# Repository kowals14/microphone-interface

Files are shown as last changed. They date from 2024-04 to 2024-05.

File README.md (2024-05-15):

# USB Microphone Interface
This repository holds all the necessary files for [team 12's ECE 477 project](https://engineering.purdue.edu/477grp12/).

## Project Description
Microphone Interface is a microphone interface intended to be used with analog audio microphones. This interface would apply various DSP effects to the audio and pass it to an analog output. Specifically, our device will implement the following functionality:
* Be powered via micro-USB.
* Receive an analog audio input via 3.5mm TRS jack.
* Apply the following user selectable and user controllable DSP effects:
    * Five band equalization
    * Distortion
    * Delay
*  Allow the user to navigate backwards and formwards via two push buttons.
*   Allow the user to manipulate the following DSP parameters via three rotary encoders:
    * Equalization (for each band):
      * Frequency
      * Width
      * Gain
    * Distortion:
      * Pre-Amp
      * Gain
      * Mix
    * Delay:
      * Time
      * Feedback
      * Mix
* Display the states of each DSP parameter (with a separate page for each effect) via a graphical user interface.
* Output the modified audio signal via a 3.5mm TRS jack.
  
## PROJECT SPECIFIC DESIGN REQUIREMENTS (PSDRS):
* PSDR #1 (Hardware): An ability to send and receive an audio signal to and from a codec and a microcontroller via I2S.
* PSDR #2 (Software): An ability to apply five band EQ, distortion, and delay effects via DSP on an input audio.
* PSDR #3 (Hardware): An ability to control DSP parameters using input to a microcontroller from a set of rotary encoders and buttons.
* PSDR #4 (Hardware): An ability for the microcontroller to interface with an LCD display via SPI.
* PSDR #5 (Software): An ability to provide a GUI to display DSP parameters and corresponding audio effects.

## STRETCH PSDRS:
* PSDR #6 (hardware): An ability to control parameters and interact with the user interface via capacitive touch screen.

## Files
* Final - STM32 Cube project containing the final version of the project.
* Current - Folder containing schematic and pcb files for Kicad

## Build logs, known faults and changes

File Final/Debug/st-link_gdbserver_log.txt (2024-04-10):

[0.000] initConfigParams():  Configuration flags start
[0.001] initConfigParams():   external-init                  false
[0.001] initConfigParams():   pend-halt-timeout              (null)
[0.001] initConfigParams():   halt                           false
[0.001] initConfigParams():   config-file                    ""
[0.001] initConfigParams():   persistent                     false
[0.001] initConfigParams():  +log-file                       "C:\Users\Kuba\STM32CubeIDE\workspace_1.14.0\Final\Debug\st-link_gdbserver_log.txt"
[0.001] initConfigParams():  +log-level                      31
[0.001] initConfigParams():  +port-number                    61234
[0.001] initConfigParams():  +verbose                        true
[0.001] initConfigParams():   refresh-delay                  15
[0.001] initConfigParams():  +verify                         true
[0.001] initConfigParams():  +swd                            true
[0.001] initConfigParams():   swo-port                       61234
[0.001] initConfigParams():   cpu-clock                      8000000
[0.001] initConfigParams():   swo-clock-div                  128
[0.001] initConfigParams():  +initialize-reset               true
[0.001] initConfigParams():   debuggers                      false
[0.001] initConfigParams():   serial-number                  ""
[0.001] initConfigParams():  +apid                           0
[0.001] initConfigParams():   attach                         false
[0.001] initConfigParams():   shared                         false
[0.001] initConfigParams():   erase-all                      false
[0.001] initConfigParams():   memory-map                     ""
[0.001] initConfigParams():   ext-memory-loaders             false
[0.001] initConfigParams():   extload_init                   (null)
[0.001] initConfigParams():   extload                        (null)
[0.001] initConfigParams():  +stm32cubeprogrammer-path       "C:\ST\STM32CubeIDE_1.14.0\STM32CubeIDE\plugins\com.st.stm32cube.ide.mcu.externaltools.cubeprogrammer.win32_2.1.100.202311100844\tools\bin"
[0.001] initConfigParams():   temp-path                      ""
[0.001] initConfigParams():   preserve-temps                 false
[0.001] initConfigParams():   frequency                      0
[0.001] initConfigParams():   licenses                       false
[0.001] initConfigParams():   ignore-rest                    false
[0.001] initConfigParams():   version                        false
[0.001] initConfigParams():   help                           false
[0.001] initConfigParams():  Configuration flags end
[0.004] init():  STMicroelectronics ST-LINK GDB server. Version 7.5.0
Copyright (c) 2023, STMicroelectronics. All rights reserved.
[0.022] openDevice():  COM frequency = 4000 kHz
[0.022] openDevice():  Target connection mode: Under reset
[0.545] readFromTarget():  Reading ROM table for AP 0 @0xe00fdfd0
[0.548] reset_hw_wtchpt_module():  Hardware watchpoint supported by the target 
[0.552] initContext():  ST-LINK Firmware version : V2J43S7
[0.552] initContext():  Device ID: 0x449
[0.552] initContext():  PC: 0x8002bb8
[0.552] Device_GetStatus():  ST-LINK device status: HALT_MODE
[0.553] initContext():  ST-LINK detects target voltage = 3.32 V
[0.553] initContext():  ST-LINK device status: HALT_MODE
[0.553] initServerContext():  ST-LINK device initialization OK
[0.553] pollAndNotifyRun():  Stm32Device, pollAndNotify running...
[0.555] updateState():  SwvSrv state change: 0 -> 1
[0.555] WaitConnection():  Waiting for connection on port 61234...
[0.555] WaitConnection():  Waiting for connection on port 61235...
[4.307] WaitConnection():  Accepted connection on port 61234...
[4.307] WaitConnection():  Waiting for connection on port 61234...
[4.307] run():  GDB session thread running
[4.307] handleSessionEvent():  GdbSessionManager, session started: 1
[4.322] read():  <756> Rx: +
[4.322] read():  <756> Rx: $qSupported:multiprocess+;swbreak+;hwbreak+;qRelocInsn+;fork-events+;vfork-events+;exec-events+;vContSupported+;QThreadEvents+;no-resumed+;memory-tagging+#ec
[4.322] write():  <756> Tx: +
[4.322] write():  <756> Tx: $PacketSize=4000;qXfer:memory-map:read+;qXfer:features:read+;QStartNoAckMode+;QNonStop+;qXfer:threads:read+;hwbreak+;swbreak+#f3
[4.322] read():  <756> Rx: +
[4.322] read():  <756> Rx: $vMustReplyEmpty#3a
[4.322] write():  <756> Tx: +
[4.322] write():  <756> Tx: $#00
[4.322] read():  <756> Rx: +$QStartNoAckMode#b0
[4.338] write():  <756> Tx: +
[4.338] write():  <756> Tx: $OK#9a
[4.338] read():  <756> Rx: +
[4.338] read():  <756> Rx: $Hg0#df
[4.338] write():  <756> Tx: $#00
[4.338] read():  <756> Rx: $qXfer:features:read:target.xml:0,1000#0c
[4.338] write():  <756> Tx: $l<?xml version="1.0"?><!-- Copyright (C) 2009, 2010, 2011 Free Software Foundation, Inc.     Copying and distribution of this file, with or without modification,     are permitted in any medium without royalty provided the copyright     notice and this notice are preserved.  --><!DOCTYPE target SYSTEM "gdb-target.dtd"><target><feature name="org.gnu.gdb.arm.m-profile">  <reg name="r0" bitsize="32"/>  <reg name="r1" bitsize="32"/>  <reg name="r2" bitsize="32"/>  <reg name="r3" bitsize="32"/>  <reg name="r4" bitsize="32"/>  <reg name="r5" bitsize="32"/>  <reg name="r6" bitsize="32"/>  <reg name="r7" bitsize="32"/>  <reg name="r8" bitsize="32"/>  <reg name="r9" bitsize="32"/>  <reg name="r10" bitsize="32"/>  <reg name="r11" bitsize="32"/>  <reg name="r12" bitsize="32"/>  <reg name="sp" bitsize="32" type="data_ptr"/>  <reg name="lr" bitsize="32"/>  <reg name="pc" bitsize="32" type="code_ptr"/>  <reg name="xpsr" bitsize="32" regnum="25"/></feature><feature name="org.gnu.gdb.arm.vfp">  <reg name="d0" bitsize="64" type="ieee_double"/>  <reg name="d1" bitsize="64" type="ieee_double"/>  <reg name="d2" bitsize="64" type="ieee_double"/>  <reg name="d3" bitsize="64" type="ieee_double"/>  <reg name="d4" bitsize="64" type="ieee_double"/>  <reg name="d5" bitsize="64" type="ieee_double"/>  <reg name="d6" bitsize="64" type="ieee_double"/>  <reg name="d7" bitsize="64" type="ieee_double"/>  <reg name="d8" bitsize="64" type="ieee_double"/>  <reg name="d9" bitsize="64" type="ieee_double"/>  <reg name="d10" bitsize="64" type="ieee_double"/>  <reg name="d11" bitsize="64" type="ieee_double"/>  <reg name="d12" bitsize="64" type="ieee_double"/>  <reg name="d13" bitsize="64" type="ieee_double"/>  <reg name="d14" bitsize="64" type="ieee_double"/>  <reg name="d15" bitsize="64" type="ieee_double"/>  <reg name="fpscr" bitsize="32" type="int" group="float"/></feature><feature name="org.gnu.gdb.arm.m-system">  <reg name="primask" bitsize="32" regnum="93"/>  <reg name="basepri" bitsize="32" regnum="94"/>  <reg name="faultmask" bitsize="32" regnum="95"/>  <reg name="control" bitsize="32" regnum="96"/>  <reg name="msp" bitsize="32" type="data_ptr" regnum="97"/>  <reg name="psp" bitsize="32" type="data_ptr" regnum="98"/></feature></target>#ad
[4.340] read():  <756> Rx: $QNonStop:0#8c
[4.340] write():  <756> Tx: $OK#9a
[4.340] read():  <756> Rx: $qTStatus#49
[4.340] write():  <756> Tx: $#00
[4.340] read():  <756> Rx: $?#3f
[4.340] write():  <756> Tx: $S05#b8
[4.341] read():  <756> Rx: $qXfer:threads:read::0,1000#92
[4.341] write():  <756> Tx: $l<?xml version="1.0"?><threads><thread id="1" core="0" name="main"></thread></threads>#f7
[4.341] read():  <756> Rx: $qAttached#8f
[4.341] write():  <756> Tx: $#00
[4.341] read():  <756> Rx: $Hc-1#09
[4.341] write():  <756> Tx: $#00
[4.341] read():  <756> Rx: $qC#b4
[4.341] write():  <756> Tx: $QC1#c5
[4.341] read():  <756> Rx: $qOffsets#4b
[4.341] write():  <756> Tx: $#00
[4.342] read():  <756> Rx: $g#67
[4.352] write():  <756> Tx: $0000000000000000000000000000000000000000000000000000000000000000000000000000000000000000000000000000000000000520ffffffffb82b000800000001000000000000000000000000000000000000000000000000000000000000000000000000000000000000000000000000000000000000000000000000ffffffff000000000000000000000000000000000000000000000000000000000000000000000000000000000000000000000000000000000000000000000000ffffffff00000000000000000000000000000000000000000000052000000000#95
[4.352] read():  <756> Rx: $qXfer:memory-map:read::0,1000#ab
[4.352] write():  <756> Tx: $l<?xml version="1.0"?>\x0a<!DOCTYPE memory-map\x0a          PUBLIC "+//IDN gnu.org//DTD GDB Memory Map V1.0//EN"\x0a                 "http://sourceware.org/gdb/gdb-memory-map.dtd">\x0a<memory-map>\x0a<memory type="ram" start="0x0" length="0x200000"/>\x0a<memory type="flash" start="0x200000" length="0x100000">\x0a<property name="blocksize">0x8000</property>\x0a</memory>\x0a<memory type="ram" start="0x300000" length="0x7d00000"/>\x0a<memory type="flash" start="0x8000000" length="0x100000">\x0a<property name="blocksize">0x8000</property>\x0a</memory>\x0a<memory type="ram" start="0x8100000" length="0xf7efffff"/>\x0a</memory-map>#bd
[4.353] read():  <756> Rx: $m8020228,2#31
[4.353] handlePacket():  Reading 0x2 bytes of memory from addr 0x8020228 
[4.353] write():  <756> Tx: $022c#f7
[4.354] read():  <756> Rx: $qXfer:threads:read::0,1000#92
[4.354] write():  <756> Tx: $l<?xml version="1.0"?><threads><thread id="1" core="0" name="main"></thread></threads>#f7
[4.354] read():  <756> Rx: $m8002bb8,4#93
[4.354] handlePacket():  Reading 0x4 bytes of memory from addr 0x8002bb8 
[4.354] write():  <756> Tx: $dff834d0#63
[4.355] read():  <756> Rx: $m8002bb8,2#91
[4.355] handlePacket():  Reading 0x2 bytes of memory from addr 0x8002bb8 
[4.355] write():  <756> Tx: $dff8#68
[4.356] read():  <756> Rx: $m8002bba,2#ba
[4.356] handlePacket():  Reading 0x2 bytes of memory from addr 0x8002bba 
[4.356] write():  <756> Tx: $34d0#fb
[4.357] read():  <756> Rx: $qSymbol::#5b
[4.357] write():  <756> Tx: $#00
[4.358] read():  <756> Rx: $qXfer:threads:read::0,1000#92
[4.358] write():  <756> Tx: $l<?xml version="1.0"?><threads><thread id="1" core="0" name="main"></thread></threads>#f7
[4.358] read():  <756> Rx: $qRcmd,5265616441504578203078302030784638#08
[4.359] write():  <756> Tx: $4f2e4b2e3a307865303066643030330a#88
[4.359] read():  <756> Rx: $qXfer:threads:read::0,1000#92
[4.359] write():  <756> Tx: $l<?xml version="1.0"?><threads><thread id="1" core="0" name="main"></thread></threads>#f7
[4.360] read():  <756> Rx: $qRcmd,526561644d656d41502030783020307845303046444644302030783820307830#64
[4.361] write():  <756> Tx: $4f2e4b2e3a3078302c3078302c3078302c3078302c307834392c3078342c307831612c3078300a#1a
[4.400] read():  <756> Rx: $qXfer:threads:read::0,1000#92
[4.400] write():  <756> Tx: $l<?xml version="1.0"?><threads><thread id="1" core="0" name="main"></thread></threads>#f7
[4.400] read():  <756> Rx: $qXfer:threads:read::0,1000#92
[4.400] write():  <756> Tx: $l<?xml version="1.0"?><threads><thread id="1" core="0" name="main"></thread></threads>#f7
[6.411] WaitConnection():  Accepted connection on port 61234...
[6.411] WaitConnection():  Waiting for connection on port 61234...
[6.411] run():  GDB session thread running
[6.411] handleSessionEvent():  GdbSessionManager, session started: 2
[6.427] read():  <788> Rx: +
[6.427] read():  <788> Rx: $qSupported:multiprocess+;swbreak+;hwbreak+;qRelocInsn+;fork-events+;vfork-events+;exec-events+;vContSupported+;QThreadEvents+;no-resumed+;memory-tagging+#ec
[6.427] write():  <788> Tx: +
[6.427] write():  <788> Tx: $PacketSize=4000;qXfer:memory-map:read+;qXfer:features:read+;QStartNoAckMode+;QNonStop+;qXfer:threads:read+;hwbreak+;swbreak+#f3
[6.427] read():  <788> Rx: +$vMustReplyEmpty#3a
[6.442] write():  <788> Tx: +
[6.442] write():  <788> Tx: $#00
[6.442] read():  <788> Rx: +
[6.442] read():  <788> Rx: $QStartNoAckMode#b0
[6.442] write():  <788> Tx: +
[6.442] write():  <788> Tx: $OK#9a
[6.442] read():  <788> Rx: +$Hg0#df
[6.457] write():  <788> Tx: $#00
[6.457] read():  <788> Rx: $qXfer:features:read:target.xml:0,1000#0c
[6.457] write():  <788> Tx: $l<?xml version="1.0"?><!-- Copyright (C) 2009, 2010, 2011 Free Software Foundation, Inc.     Copying and distribution of this file, with or without modification,     are permitted in any medium without royalty provided the copyright     notice and this notice are preserved.  --><!DOCTYPE target SYSTEM "gdb-target.dtd"><target><feature name="org.gnu.gdb.arm.m-profile">  <reg name="r0" bitsize="32"/>  <reg name="r1" bitsize="32"/>  <reg name="r2" bitsize="32"/>  <reg name="r3" bitsize="32"/>  <reg name="r4" bitsize="32"/>  <reg name="r5" bitsize="32"/>  <reg name="r6" bitsize="32"/>  <reg name="r7" bitsize="32"/>  <reg name="r8" bitsize="32"/>  <reg name="r9" bitsize="32"/>  <reg name="r10" bitsize="32"/>  <reg name="r11" bitsize="32"/>  <reg name="r12" bitsize="32"/>  <reg name="sp" bitsize="32" type="data_ptr"/>  <reg name="lr" bitsize="32"/>  <reg name="pc" bitsize="32" type="code_ptr"/>  <reg name="xpsr" bitsize="32" regnum="25"/></feature><feature name="org.gnu.gdb.arm.vfp">  <reg name="d0" bitsize="64" type="ieee_double"/>  <reg name="d1" bitsize="64" type="ieee_double"/>  <reg name="d2" bitsize="64" type="ieee_double"/>  <reg name="d3" bitsize="64" type="ieee_double"/>  <reg name="d4" bitsize="64" type="ieee_double"/>  <reg name="d5" bitsize="64" type="ieee_double"/>  <reg name="d6" bitsize="64" type="ieee_double"/>  <reg name="d7" bitsize="64" type="ieee_double"/>  <reg name="d8" bitsize="64" type="ieee_double"/>  <reg name="d9" bitsize="64" type="ieee_double"/>  <reg name="d10" bitsize="64" type="ieee_double"/>  <reg name="d11" bitsize="64" type="ieee_double"/>  <reg name="d12" bitsize="64" type="ieee_double"/>  <reg name="d13" bitsize="64" type="ieee_double"/>  <reg name="d14" bitsize="64" type="ieee_double"/>  <reg name="d15" bitsize="64" type="ieee_double"/>  <reg name="fpscr" bitsize="32" type="int" group="float"/></feature><feature name="org.gnu.gdb.arm.m-system">  <reg name="primask" bitsize="32" regnum="93"/>  <reg name="basepri" bitsize="32" regnum="94"/>  <reg name="faultmask" bitsize="32" regnum="95"/>  <reg name="control" bitsize="32" regnum="96"/>  <reg name="msp" bitsize="32" type="data_ptr" regnum="97"/>  <reg name="psp" bitsize="32" type="data_ptr" regnum="98"/></feature></target>#ad
[6.458] read():  <788> Rx: $QNonStop:0#8c
[6.458] write():  <788> Tx: $OK#9a
[6.459] read():  <788> Rx: $qTStatus#49
[6.459] write():  <788> Tx: $#00
[6.459] read():  <788> Rx: $?#3f
[6.459] write():  <788> Tx: $S05#b8
[6.459] read():  <788> Rx: $qXfer:threads:read::0,1000#92
[6.459] write():  <788> Tx: $l<?xml version="1.0"?><threads><thread id="1" core="0" name="main"></thread></threads>#f7
[6.459] read():  <788> Rx: $qAttached#8f
[6.459] write():  <788> Tx: $#00
[6.459] read():  <788> Rx: $Hc-1#09
[6.460] write():  <788> Tx: $#00
[6.460] read():  <788> Rx: $qC#b4
[6.460] write():  <788> Tx: $QC1#c5
[6.460] read():  <788> Rx: $qOffsets#4b
[6.460] write():  <788> Tx: $#00
[6.460] read():  <788> Rx: $g#67
[6.471] write():  <788> Tx: $0000000000000000000000000000000000000000000000000000000000000000000000000000000000000000000000000000000000000520ffffffffb82b000800000001000000000000000000000000000000000000000000000000000000000000000000000000000000000000000000000000000000000000000000000000ffffffff000000000000000000000000000000000000000000000000000000000000000000000000000000000000000000000000000000000000000000000000ffffffff00000000000000000000000000000000000000000000052000000000#95
[6.471] read():  <788> Rx: $qXfer:memory-map:read::0,1000#ab
[6.472] write():  <788> Tx: $l<?xml version="1.0"?>\x0a<!DOCTYPE memory-map\x0a          PUBLIC "+//IDN gnu.org//DTD GDB Memory Map V1.0//EN"\x0a                 "http://sourceware.org/gdb/gdb-memory-map.dtd">\x0a<memory-map>\x0a<memory type="ram" start="0x0" length="0x200000"/>\x0a<memory type="flash" start="0x200000" length="0x100000">\x0a<property name="blocksize">0x8000</property>\x0a</memory>\x0a<memory type="ram" start="0x300000" length="0x7d00000"/>\x0a<memory type="flash" start="0x8000000" length="0x100000">\x0a<property name="blocksize">0x8000</property>\x0a</memory>\x0a<memory type="ram" start="0x8100000" length="0xf7efffff"/>\x0a</memory-map>#bd
[6.472] read():  <788> Rx: $m8020228,2#31
[6.472] handlePacket():  Reading 0x2 bytes of memory from addr 0x8020228 
[6.473] write():  <788> Tx: $022c#f7
[6.473] read():  <788> Rx: $qXfer:threads:read::0,1000#92
[6.473] write():  <788> Tx: $l<?xml version="1.0"?><threads><thread id="1" core="0" name="main"></thread></threads>#f7
[6.474] read():  <788> Rx: $m8002bb8,4#93
[6.474] handlePacket():  Reading 0x4 bytes of memory from addr 0x8002bb8 
[6.474] write():  <788> Tx: $dff834d0#63
[6.475] read():  <788> Rx: $m8002bb8,2#91
[6.475] handlePacket():  Reading 0x2 bytes of memory from addr 0x8002bb8 
[6.475] write():  <788> Tx: $dff8#68
[6.475] read():  <788> Rx: $m8002bba,2#ba
[6.476] handlePacket():  Reading 0x2 bytes of memory from addr 0x8002bba 
[6.476] write():  <788> Tx: $34d0#fb
[6.477] read():  <788> Rx: $qSymbol::#5b
[6.477] write():  <788> Tx: $#00
[6.504] read():  <756> Rx: $vFlashErase:08000000,00028000#cc
[6.504] handleFlashPacket():  FlashErase skipped (Will be performed at flash done)
[6.504] write():  <756> Tx: $OK#9a
[6.504] read():  <756> Rx: $vFlashWrite:8000000:\x00\x00\x05 \xff+\x00\x08y)\x00\x08\x7f)\x00\x08\xff)\x00\x08\xff)\x00\x08\xff)\x00\x08\x00\x00\x00\x00\x00\x00\x00\x00\x00\x00\x00\x00\x00\x00\x00\x00\xff)\x00\x08\xff)\x00\x08\x00\x00\x00\x00\xff)\x00\x08\xff)\x00\x08\x09,\x00\x08\x09,\x00\x08\x09,\x00\x08\x09,\x00\x08\x09,\x00\x08\xff)\x00\x08\x09,\x00\x08\x09,\x00\x08\x09,\x00\x08\x09,\x00\x08\x09,\x00\x08\x09,\x00\x08\x09,\x00\x08\x09,\x00\x08\x09,\x00\x08\x09,\x00\x08\x09,\x00\x08\x09,\x00\x08\x09,\x00\x08\x09,\x00\x08\x09,\x00\x08\x09,\x00\x08\x09,\x00\x08\x09,\x00\x08\x09,\x00\x08\x09,\x00\x08\x09,\x00\x08\x09,\x00\x08\xff)\x00\x08\x09,\x00\x08\x09,\x00\x08\x09,\x00\x08\x09,\x00\x08\x09,\x00\x08\x09,\x00\x08\x09,\x00\x08\x09,\x00\x08\x09,\x00\x08\x09,\x00\x08\x09,\x00\x08\x09,\x00\x08\x09,\x00\x08\x09,\x00\x08\x09,\x00\x08\x09,\x00\x08\xff)\x00\x08\x09,\x00\x08\x09,\x00\x08\x09,\x00\x08\x09,\x00\x08\x09,\x00\x08\x09,\x00\x08\x09,\x00\x08\x09,\x00\x08\x09,\x00\x08\x09,\x00\x08\x09,\x00\x08\x05}\x0a\x00\x08\x09,\x00\x08\x09,\x00\x08\x19}\x0a\x00\x08\x09,\x00\x08\x09,\x00\x08\x09,\x00\x08\x09,\x00\x08\x09,\x00\x08\x09,\x00\x08\x09,\x00\x08-}\x0a\x00\x08\x09,\x00\x08\x09,\x00\x08\x09,\x00\x08\x09,\x00\x08\x09,\x00\x08\x09,\x00\x08\x09,\x00\x08\x09,\x00\x08\x09,\x00\x08\x09,\x00\x08\x00\x00\x00\x00\x09,\x00\x08\x09,\x00\x08\x09,\x00\x08\x09,\x00\x08\x09,\x00\x08\x09,\x00\x08\x09,\x00\x08\x09,\x00\x08\x09,\x00\x08\x09,\x00\x08\x09,\x00\x08\x09,\x00\x08\x09,\x00\x08\x09,\x00\x08\x09,\x00\x08\x09,\x00\x08\x09,\x00\x08\x09,\x00\x08#23
[6.505] handleFlashPacket():  Flash write: Address= 0x8000000, Length=456
[6.505] write():  <756> Tx: $OK#9a
[6.506] read():  <756> Rx: $vFlashWrite:80001d0:\x10\xff\x05L}\x03x3\xff\x04K\x13\xff\x04H\xff\xff\x00\xff\x01}\x03}\x03p\x10\xff0\x01\x00 \x00\x00\x00\x00l:\x02\x08\x08\xff\x03K\x1b\xff\x03I\x03H\xff\xff\x00\xff\x08\xff\x00\x00\x00\x004\x01\x00 l:\x02\x08\x01\xff\xff\x01\x10}\x0a+\xff\x10\xff\x07\x0f\x08\xff\x10\xff\x01;\x01:\xffB-\xff\x10\xff\x07\x0fB\xff\xff\xff\xff\xffA\xff\x01!A\xff\x01A"\xff\x07\x04\x7f\xff\x00\x07\x00}\x03\xff\xff\x02V\x08<\xff\xff\x01\x05\xff\xff\x01\x06\xff\xffG\xff\xff\xff\xff\xff\xff\xffG\xff\xff\xff\xff\xff\xff\xff\xff\xff\xff\xff\x01\xff\xff\x01\x02\xff\x07\x022\xff\x10\xff\x01;\x01:\xff\xff\x01\x03\x13\xff\xff\xff\x00 pG\x018pG\x00-\x06\xff5F\x038\x078\x15\xff\x01\x0f\x07\xff\x010\x15\xff\xff\x7f\x02\xff\x010\x15\xff\xff?\x010\xff\xff\x018pG\x00\xff\xff\xff\x00A\x02\xff\x00\xff\xff\xff\x00C0\xffO\xffA\x04O\xffC\x05\xff\xff\x05\x0f\x08\xff\xff\xff\x02\x0f\x1f\xffT\xff\x00\x0cU\xff\x02\x0c\x7f\xffd\\\x7f\xffe\\\x00\xff\xff\xffO\xffTT\xff\xffUU\xff\xffmB\x0c\xff,D\xff\xff\x02\x02\xff\xff\x03\x03\xff\xff\x00\x00\xff\xff\x01\x01\xff\xff\x02\x02\xff\xff\x03\x036-\xff\xff0\xff\x11\xff\x00OO\xff\x011O\xff\xff\x1cL\xff\x111\x02\xff@Ba\xffA\x01\x13\xff\x00OO\xff\x033L\xff\x133\x02\xffRBc\xffC\x03\xff\xff\x05\x0f\x00\xff\xff\xff\xff\xff\x01\x04\xff\xff \x0e\x0d\xff\x02\xff\x0e\xff"\xff\x05\xff\xff\x18A\xff\x00\x01\x03\xff\x0e\xff\xff\x18C\xff\x05\xffYA\x0e\xff\xff\xff \x05\x0e\xff \x0e\x01}\x0a\x03\xff\x0e\xff(\xffL\xff\x02\x0cC\xff\x05\xff\xff\x18Q\xff\xffq\x01\xff\x00E\x07\xffO\xff\x00\x0e\xff\xff\x00\x0c~\xff\x00\x00n\xff\x01\x01\xff\xff\xff\x1f\x1b\xff\xff\xff\x00\x1f\x0c\xffI\x08_\xff0\x00O\xff<\x0c\x04\xff\x01\x04O\xffDR\x12\xff\xff\x0f\xff\xff\xff\xff\xff\xff\x00O\x08\xff_\xffP\x0cP\xff\x00\x00A\xff\x04QA\xff\x05\x010\xff_\xffL\x0c@AA\xff\x01\x01\x01<(\xff\xff\xff\xff\x1f\xff\xff\xff\xff\x00\x0f\x04\xff\x01F\x00 \xff\xff\xff\xff\x08\xff 3\xff\xff\x0b\x03\xff\xff \x02\x0c\xff\x0c2\x08\xff\x02\xff\x14\x0c\xff\xff\x0c\x02\x01\xff\x0c\xff!\xff\x02\xff\x0c\xff\x02\xff\x14\x02\xff\xff\xff\xff \x0c\x01\xff\x02\xff \xff\x0c\xff\xff\xffA\xff\x0c\x01\xff@\xff\x1a\xff\xff\x01\xff\x04Q)C0\xffo\xff\x04\x04\x1f<\x1c\xff\x0c4\x0e\xff\x04\xff\x14\x04\xff\xff \x02 \xff\x04\xff\x01\xff\x02\xff@\xff\x03\x00!\xff\x04\xffE\xff\x03\x010\xff\xff\xff\x0c\x04\xff\xff \x02 \xff\x02\xff\x01\xff\x04\xff@\xff\x03\x00)F0\xff!\xff\x04\xff)F0\xff\xff\xff\x00\x0f\xff\xff\xff\x13\x06\xff\xff\xff\xff\x11\x014\x01=N\xff\x7f\xffd\\\x18\xff\x7f\xffe\\)\xff\xff\xff\x05\x0f\x08\xff\xff\xff\x02\x0f\x05\xffT\xff\x00\x0c\x04\xff\x19F\x10F0\xff\xff\xff\x03\x0f\x1e\xff\x00!\x00 0\xff_\xffT\\\x05\xff@\x00IA(\xffA\xff\x00A0\xff\x14\xff\xff\x04<\xff\x01\xff\xff\x110\xff\x01\xff\x00EE\xff\xffAA\xffp\x01O\xff\x00\x000\xff\x7f\xffd\\\x1a\xff\x19F\x10F\x7f\xffe\\\x1c\xff\x0bF\x02FP\xff\x014\x06\xffR\xff\x035\xff\xff\x03\x0fA\xff\x00!0\xff\x00\xff\xff\xff\x00\x0f\x04\xff\x00!pG0\xffO\xff\xffd\x04\xff2\x04O\xff\x00\x05O\xff\x00\x01P\xff\x00\xff\xff\xff\x00\x0f\x04\xff\x00!pG0\xffO\xff\xffd\x04\xff2\x04\x10\xff\x00EH\xff@BO\xff\x00\x01>\xff\x00\xffB\x00O\xff\xff\x01O\xff1\x01O\xff\x02p\x1f\xff\x12\xff\x7fC\xff\xff\x7fO\xff\xff`QpG2\xff\x7fB\x08\xffpG\xff\xff\x7fO\x04\xffA\xff\x00!pG0\xffO\xff`t\x01\xff\x00E!\xff\x00A\x1c\xff\x00\xffP\xff\x01\x02\x08\xffpG0\xffO\xff\x00\x05\x0a\xffP\xff\x01\x02\x08\xffpG0\xff\x11\xff\x00E\x02\xff@Ba\xffA\x01O\xff\xffd\x04\xff2\x04_\xff\xff\\?\xff\xff\xffO\xff\x03\x02_\xff\xff\x0c\x18\xff\x032_\xff\xff\x0c\x18\xff\x032\x02\xff\xff\x02\xff\xff \x03\x00\xff\x03\xff \xff\x02\xff\x01\xff\x03\xff@\xff\x0e\x00!\xff\x02\xff\x14D\xff\xff\x00\xffp\xffO\xff\xff\x0cL\xff\xffl\x1c\xff\x11T\x1d\xff\x1c\xff\x13U\xff\xff\x0c\x0f\xff\xff\x0c\x0f\x00\xff\xff\xff,D\xff\xff\x03\x06!\xffLQ}\x03\xffLSP\xff\x015\x18\xffR\xff\x035A\xff\xff\x11C\xff\xff\x138\xff\xff\xff\x02\xffO\xff\x00\x05\xff\xff\x02\xff\x06\xff\x00B\xff\xff\x03\xffO\xff\x00\x06\xff\xff\x03V\xff\xff\x00\x0f\x18\xffN\xff\x01\x0e\xff\xff\xff\x04\xff\xff\x00\x7fd\xff@t\x04\xff_\xffN\x0emAF\xff\x06\x06B\xff\xff!A\xffUQO\xff\xff @\xff^PO\xff\xff.\xff\xff\xff\x0c\xff\xff\xff\xff\xffo\x1e\xff\xff\xff\x00O\x08\xff_\xffP\x0eP\xff\x00\x00A\xff\x04Qp\xff\x06\xff\x00FF\xff\x01\x01@\xff\x02\x00\xff\xff\x03\x01\xff\xff\\\x04\xff\xff\xff\xff\x0c\x05A\xff\x04Qp\xffA\xff\xff\x11O\xff\x00\x0e\x01<\x00\xff\xff\xff\x14\xff6\x0f\xff\xff\x00 \x01\xff\x00Ap\xff\xff\xff\x00\x04 <5\xff\x0c4\x1b\xff\x04\xff\x14\x04\xff\xff \x05\x00\xff\x05\xff \xff\x04\xff\x01\xff\x05\xff@\xff\x02\x00\x01\xff\x00B!\xff\x00A\x10\xff\xffp!\xff\x04\xffB\xff\x06\x01^\xffC\x0e\x08\xff \xff\xffpp\xff\xff\xff\x0c\x04\xff\xff \x05\x00\xff\x04\xff \xff\x05\xff\x01\xff\x04\xff@\xff\x02\x00\x01\xff\x00A\x10\xff\xffpA\xff\x00\x01^\xffC\x0e\x08\xff \xff\xffpp\xff\xff\xff \x05\x00\xff\x05\xffN\xff\x02\x0e \xff\x04\xff\x01\xff\x05\xffC\xff\x02\x03!\xff\x04\xff\x01\xff\x00A!\xff\x04\xff \xff\x02\x00\x00\xff\xffp^\xffC\x0e\x08\xff \xff\xffpp\xff\xff\xff\x00\x0f\x0f\xff\x01\xff\x00F@\x00A\xff\x01\x01\x11\xff\xff\x1f\x08\xff\x01<\xff\xffA\xff\x06\x01\xff\xff\x00\x0f\x18\xffpG\x03\xff\x00FR\x00C\xff\x03\x03\x13\xff\xff\x1f\x08\xff\x01=\xff\xffC\xff\x06\x03pG\xff\xff\x0c\x0f\x0c\xff\x13U\x18\xff\xff\xff\x0c\x0f\x0c\xffP\xffA\x06\x18\xffR\xffC\x06\xff\xff\xff\xff\x03\x01\x01\xff\x00AO\xff\x00\x00p\xffP\xffA\x06\x06\xff\x10F\x19FR\xffC\x06\x19\xff\xff\xff\x0c\x0f\x02\xffP\xff\x016\x13\xff\xff\xff\x0c\x0f\x05\xffR\xff\x036\x1c\xff\x10F\x19F\x0a\xff\xff\xff\x03\x01\x01\xff\x00AA\xff\xffAA\xffp\x01O\xff\x00\x00p\xffA\xff\xffAA\xffx\x01p\xffp\xffO\xff\xff\x0cL\xff\xffl\x1c\xff\x11T\x1d\xff\x1c\xff\x13U\xff\xff\x0c\x0f\xff\xff\x0c\x0f\x00\xff\xff\xff\xff\xff\x05\x04\xff\xff\x03\x0eR\xff\x035O\xff\x011\x00\xff\xff\xffO\xff\x033O\xff\xffUE\xff\x13\x13C\xff\x12cO\xff\x02"E\xff\x11\x15E\xff\x10eO\xff\x00&\x0e\xff\x00A\xffB\x08\xff\xffBD\xff\xff\x04\x04\xff@t\x02\xff[\x08O\xff2\x02\xff\x1ae\xff\x03\x05[\x08O\xff2\x02O\xff\xff\x10O\xff\x00,\xff\xff\x02\x0eu\xff\x03\x0e"\xff\xff\x1auF@\xff\x0c\x00[\x08O\xff2\x02\xff\xff\x02\x0eu\xff\x03\x0e"\xff\xff\x1auF@\xff\\\x00[\x08O\xff2\x02\xff\xff\x02\x0eu\xff\x03\x0e"\xff\xff\x1auF@\xff\xff\x00[\x08O\xff2\x02\xff\xff\x02\x0eu\xff\x03\x0e"\xff\xff\x1auF@\xff\xff\x00U\xff\x06\x0e\x18\xffO\xff\x05\x15E\xff\x16uO\xff\x06\x16O\xff\xff\x03C\xffRsO\xff\xff\x02_\xff\x1c\x1c\xff\xff\x11\xff\xff\x1f\x0b\xffA\xff\x00\x01O\xff\x00\x00O\xff\x00L\xff\xff\x11\xff\xff\x1f\x04\xff\x01C\x00 \xff\xff\xff\x0c\xff\xff\xff\xff\xffo?\xff\xff\xff\xff\xff\x03\x0c\x04\xff\xff\xff\x02\x0c_\xffP\x0cP\xff\x00\x00A\xff\x04Qp\xff\x0e\xff\x00NN\xff\x111\x14\xff\\\x04\xff\xff\xff\xff\x0c\x05A\xff\x04Qp\xffA\xff\xff\x11O\xff\x00\x0e\x01<\xff\xffE\xff\x06\x0e\xff\xff\x0c\xff\x13U\xff\xff\x0c\x0f\x08\xff\xff\xff\x0c\x0f?\xff;\xff\xff\xff\x0c\x0f\x0a\xffP\xff\x014\x7f\xff4\xff\xff\xff\x0c\x0f\x7f\xff%\xff\x10F\x19F,\xff\xff\xff\x0c\x0f\x06\xffR\xff\x035?\xff\xff\xff\x10F\x19F"\xffP\xffA\x06\x18\xffR\xffC\x06\x7f\xff\xff\xffP\xffA\x04\x7f\xff\x0d\xffR\xffC\x05\x7f\xff\xff\xff\x12\xffO\xff\xff<\x06\xff\x00\xffO\xff\x01\x0c\x02\xff\x00\xffO\xff\x01\x0cM\xff\x04\xffO\xffA\x0c\x7f\xffl\\O\xffC\x0c\x18\xff\x7f\xffl\\\x1b\xff\x01\xffP\xffA\x0c\x0c\xffR\xffC\x0c\xff\xff\x03\x0f\x02\xff\xff\xff\x02\x0f\x00 pG\x10\xff\x00\x0f\xff\xff\x03\x0fX\xff\xffB\x08\xff\xffB,\xff\xff\x17o\xff\xffp@\xff\x01\x00pGO\xffA\x0c\x7f\xffl\\\x02\xffP\xff\x01<\x07\xffO\xffC\x0c\x7f\xffl\\\xff\xffR\xff\x03<\xff\xff]\xff\x04\x0bpG\x00\xff\xffF\x10FbF\xffF\x19FcF\x00\xff\x00\xff\x01\xff\xff\xff\xff\xff\x00(H\xff\x10\xff\x00\x0f\x01\xffM\xff\x08\xff\xff\xff\xff\xff\x0c\xff\x01 \x00 ]\xff\x08\xff\x00\xffM\xff\x08\xff\xff\xff\xff\xff4\xff\x01 \x00 ]\xff\x08\xff\x00\xffM\xff\x08\xff\xff\xff\xff\xff\xff\xff\x01 \x00 ]\xff\x08\xff\x00\xffM\xff\x08\xff\xff\xff\xff\xff\xff\xff\x01 \x00 ]\xff\x08\xff\x00\xffM\xff\x08\xff\xff\xff\xff\xff4\xff\x01 \x00 ]\xff\x08\xff\x00\xffO\xffA\x0c\x7f\xffl\\\x02\xffP\xff\x01<\x0a\xffO\xffC\x0c\x7f\xffl\\\x02\xffR\xff\x03<\x02\xffO\xff\x00\x00pGO\xff\x01\x00pGO\xffA\x02\x12\xff\x00\x12\x15\xff\x11\xffo\xffxs\xff\xffbR\x12\xffO\xff\xff}\x03C\xff\x00CC\xffPS\x11\xff\x00O}\x03\xff\x02\xff\x18\xff@BpGO\xff\x00\x00pGP\xff\x010\x05\xff\x11\xff\x00@\x08\xffo\xff\x00@pGO\xff\x00\x00pG\x00\xffJ\x00\x11\xff\x12\xff\x00\x12\x11\xff\x0d\xffo\xffxs\xff\xffbR\x0e\xffO\xff\xff}\x03C\xff\x00CC\xffPS}\x03\xff\x02\xffpGO\xff\x00\x00pGP\xff\x010\x02\xffO\xff\xff0pGO\xff\x00\x00pGO\xffA\x02\xff\xff\xffC}\x04\xff\xff\xff\x00\x1c\xff\xff\xff\\\x0d\xff\x01\xff\x00LO\xff\xff\x02L\xffPp\xff\xff\x00O@\xff\xff\x00\x08\xff \xff\x01\x00pG\x11\xff\xffO!\xff\x13\xff8r\xff\xff\x01\xff\x00@pGA\xff\xff\x11O\xffRR\xff\xff\x18\x02\xff\xff \x0c\x10\xff\x0c\xff \xff\x02\xff\x18\xff@\xff\x01\x00O\xff\xff}\x03O\xff\xff}\x03\x03\xff\x0c\xff@\xff\x0c\x00}\x03\xff\x02\xffO\xffC\x03\xff\xff\x7f\xffbS\x07\xffP\xff\x013\x1e\xffO\xff\xff@@\xff@\x00pG\x01\xff\x00@@\xff\xff@@\xff\x00\x00pG\x00\xffS\xffJ\xff\x00)\x08\xff\x00(\x1c\xffO\xff\xff1O\xff\xff0\x00\xffp\xff\xff\xff\x08\x0cm\xff\x04\xff\x00\xff\x06\xff\xff\xff\x04\xff\xff\xff\x02}\x03\x04\xffpG-\xff\xffG\x08\xff\x0dF\x04F\x0fF\x00+J\xff\xffB\xffFe\xff\xff\xff\xff\xffC\xff\x02\xff\x03\xff\xff\xff \x02\xff@ \xff\x02\xff\x17C\xff@O\xff\x1cN\x1f\xff\xff\xff\xff\xff\xff\xff"\x0c\x0e\xff\x11wB\xff\x07B\x01\xff\x05\xff\xffB\x0a\xff\x1c\xff\x02\x02\x01\xff\xff7\xff\xff\x1c\xff\xffB@\xff\x19\xff\x029bD\x12\x1a\xff\xff\xff\xff\xff\xff\x0e\xff\x10"D\xff\x02D\x00\xff\x05\xff\xffB\x0a\xff\x1c\xff\x04\x04\x00\xff\xff2\xff\xff\x07\xff\xffB@\xff\x04\xffdD\x028@\xff\x01@d\x1b\x00!\x1e\xff\xff@\x00}\x03\xff\xff\x00C\xff\xff\xff\xff\xffB\x08\xff\x00.\x00\xff\xff\xff\x00!\xff\xff\x00\x05\x08F\xff\xff\xff\xff\xff\xff\xff\xff\x00)I\xff\xffB\x02\xff\xffB\x00\xff\xff\xff\xff\x1ae\xff\x03\x02\x01 \x17F\x00.\xff\xff\xff\xff\x00G\xff\xff\x02\xff\xff\xff\xff\xff\xff\xff\x00+@\xff\xff\xff\xff\x1aO\xff\x1cG\x1f\xff\xff\xff\x01!\xff\xff\xff\xff\x07\xff\x15 "\x0cB\xff\x00B\x0e\xff\x05\xff\xffB\x08\xff\x1c\xff\x02\x02\x05\xff\xff8\x02\xff\xffB\x00\xff\xff\xffEF\x12\x1a\xff\xff\xff\xff\xff\xff\x07\xff\x10"D\xff\x02D\x0e\xff\x00\xff\xffE\x08\xff\x1c\xff\x04\x04\x00\xff\xff2\x02\xff\xffE\x00\xff\xff\xff\x10F\xff\xff\x0e\x04@\xff\x05@\xff\xff\xff\xff \x07\xff@"\xff\x07\xffL\xff\x03\x0c\x05\xff\x01\xff \xff\x07\xff\xff@O\xff\x1cI}\x03C\xff\xff\xff\xff\x1f\xff\xff\xff\x09\xff\x18U\x1c\x0cD\xff\x05D\x08\xff\x0e\xff\xffB\x02\xff\x01\xff\x00\xff\x01\xff\x0b\xff\x1c\xff\x04\x04\x08\xff\xff:\xff\xff\xff\xff\xffB@\xff\xff\xff\xff\xff\x02\x08dDd\x1b\xff\xff\xff\xff\xff\xff\x09\xff\x13DE\xff\x04D\x03\xff\x0e\xff\xffE\x08\xff\x1c\xff\x04\x04\x03\xff\xff5l\xff\xffEj\xff\x02;dDC\xff\x08C\xff\xff\x02\xff\xff\xff\x0e\x04\xffB\xffF\xffFV\xffS\xffV\xff\xff\xff\x08\x02d\xff\x0e\x04\x04\xff\x07\xff\xff@\xff@\x17C\xff\xff\x00t\x18F\x00!\xff\xff\xff\xff\xff\xff \x01\x02\xff\x03\xff \xff\x01\xff%\xff\x01\xff\xff@}\x0aCO\xff\x1cG\x1f\xff\xff\xff\xff\xff\xff\xff\x07\xff\x10\x15\x11\x0cA\xff\x05A\x00\xff\x0e\xff\xffB\x04\xff\x03\xff\x08\xff\x1c\xff\x01\x01\x00\xff\xff8/\xff\xffB-\xff\x028aDI\x1b\xff\xff\xff\xff\xff\xff\x07\xff\x15\x11B\xff\x01B\x05\xff\x0e\xff\xffB\x08\xff\x1c\xff\x02\x02\x05\xff\xff8\x16\xff\xffB\x14\xff\x02=bDR\x1aE\xff\x00A8\xff1F0F\x08\xff9F\xff\xff\x10F\xff\xffHE\xff\xff\xff\xff\x02\x08e\xff\x0c\x0e\x01;\xff\xffEF\xff\xff+F\xff\xff@F\xff\xff\xffF{\xff\x02=bD2\xff\x08F\x0a\xffdD\x028B\xffpG\x00\xff\x00\x00\x00\x00\xff\xff\xff\xff\x00\xffx`9`\x00}\x03\xff`\x1e\xff\xffh\xff\xff\xff\xff\x12\xff\xff\xff\x00}\x03\xff\xff(\xff\x02F\x0bFC\xff\x17+;h\xff\xffG\x0a\xff\xffg\x0a\xffGQ\xff\x10\x0b\xffh\xff\x00zh\xff\x18\xff\xff\x0e\xff\x03F}\x03`\xffh\x013\xff`\xffh\xff\xff\x00o\xff\xff\x00\xff\x00\xff\x147\xffF\xff\xff\x7f5C\xff\x1f%i?-\xff\xffC\xff\xff\x00\xffx`\x0bF\xffp{h\x103\xffI\x18F\xff\xff\xff\xffzhB\xff\x10\x03\x13D\xffI\x18F\xff\xff\xff\xff{h\xffx\x1as{h\xffJ\x1a`{hO\xff\x00\x02Z`{hO\xff|R\xff`{h\x1bh{b{h[h;b{h\xffh\xffaxj\xff\xff}]\xff\xff\xff\xff\xff\x00}\x03\xff\xff\xff\xff\x02F\x0bF\x10F\x19F\xff\xff\xff\xff\x00}\x03\xff\xff\xff\xff\x02F\x0bF\x10F\x19F\xff\xff\xff\xff\x03F\xffa\xff\xff\x08z\xff\xff\xffz\xff\xff\xffj\x16\xff\xff\x0a\xff\xff]\xff\x02F\x0bFC\xff\x11+\xff\xff\xff\x0b\x1f\xff\xff\xffS\xff\x10+\x10F\x19F\xff\xff\xff\xff\x03F{a\xffi\xff\xffJ\xff\x02F\x0bFC\xff\x10+\x1f\xffL\xffS\xff\x10+\x10F\x19F\xff\xff\xff\xff\x03F;a\xffi\xff\xff9\xff\x02F\x0bFC\xff\x10+\x1f\xff\xff\xffS\xff\x10+\x10F\x19F\xff\xff}]\xff\x03F\xff`{h\x03\xff\xffC\x1aFO\xff\x00\x03\xffa{h\x03\xff\xffC\x1aFO\xff\x00\x03Sa{h\x03\xff\xffC\x1aFO\xff\x00\x03\x13a{h\x03\xff\xffC\x1aFO\xff\x00\x03\x13b{h\x03\xff\xffC\x1aFO\xff\x00\x03\xffa{h\x03\xff\xffC\x00"\xff\xffT \xffx\x02+\x00\xff\xff\xff\x02+\x00\xffY\xff\x00+\x02\xff\x01+U\xffS\xff\xff\xff\x07z7\xff\xffz\xff\xff\x03j\xff\xff\xffz\xff\xff\x02z\xff\xff\x00z\xff\xff\x04z7\xffgz\xff\xff\x00j\xff\xff&z{h\x03\xff\xffC\xff\xff\x09z\xff\xff\x00z\xff\xff\x04zw\xffgz{h\x03\xff\xffC\xff\xff\x0az\xff\xff\x00z\xff\xff\x04z7\xffgz\xff\xff\x00j\xff\xff&z{h\x03\xff\xffC\xff\xff\x0bz\xff\xff\x02z\xff\xff\x00zw\xff\xffz{h\x03\xff\xffC\xff\xff\x0cz\xff\xff\x04z\xff\xff\x00zg\xff\xffz{h\x03\xff\xffC\xff\xff\x0dz\xff\xff\x00z\xff\xff\x02zw\xffgz{h\x03\xff\xffC\xff\xff\x0ez(\xff\xff\xff\x07z7\xff\xffz\xff\xff\x03j\xff\xff\xffz\xff\xff\x02z\xff\xff\x04z\xff\xff\x00z7\xff\xffz\xff\xff\x00j\xff\xff&z{h\x03\xff\xffC\xff\xff\x09z\xff\xff\x04z\xff\xff\x00zw\xff\xffz\xff\xffgz{h\x03\xff\xffC\xff\xff\x0az\xff\xff\x04z\xff\xff\x00z7\xff\xffz\xff\xff\x00j\xff\xff&z{h\x03\xff\xffC\xff\xff\x0bz\xff\xff\x02z\xff\xff\x00zw\xff\xffz{h\x03\xff\xffC\xff\xff\x0cz\xff\xff\x04z\xff\xff\x00zg\xff\xffz{h\x03\xff\xffC\xff\xff\x0dz\xff\xff\x00z\xff\xff\x02zw\xffgz{h\x03\xff\xffC\xff\xff\x0ez\xff\xff\xff\xff\x00\xff\x18-DT\xff!\x19@\x00\x00\x00\x00\x00p\xff@\x00\x00\x00\x00\x00\x00}\x04@\xff\x03\x02\x081\x04\x02\x08\x00@\xffF\x00\x00 B\xffh\xff\xff1\xff\x04F\x0dF\xffi\xff\xff,\xff]\xff\xff\xff\x00}\x03\xff\xff\x7f\xff\x02F\x0bF\xffF\xffF\xffi\xff\xff \xff\x02F\x0bF@FIF\xff\xffr\xff\x02F\x0bF\xffF\xffF\xffh\xff\xff\x13\xff\x02F\x0bF@FIF\xff\xff\xff\xff\x02F\x0bFC\xff\x17+\xff\xffG\x0a\xff\xffg\x0a\x1e\xff\xff\xffS\xff\x10+ F)F\xff\xffU\xff\x02F\x0bF\x10F\x19F\xff\xffG\xff\x03F\xff`\xff\xff\x02z\xff\xff\x05zg\xff'z\xff\xff\x00zw\xff\xffz{h\x03\xff\xffC\xff\xff\x09z\xff\xff\x04z\xff\xff\x00zg\xff\xffz{h\x03\xff\xffC\xff\xff\x0az\xff\xff\x02z\xff\xff\x05zg\xff'z\xff\xff\x00zw\xffgz{h\x03\xff\xffC\xff\xff\x0bz\xff\xff\x02j\xff\xff\x05z\xff\xff\xffz\xff\xff\x00zw\xff\xffz{h\x03\xff\xffC\xff\xff\x0cz\xff\xff\x04z\xff\xff\x00zg\xff\xffz{h\x03\xff\xffC\xff\xff\x0dz\xff\xff\x02j\xff\xff\x05z\xff\xff\xffz\xff\xff\x00zw\xffgz{h\x03\xff\xffC\xff\xff\x0ez)\xff{h\x03\xff\xffC\x1aF{iSb{h\x03\xff\xffC\x1aFO\xff\x00\x03\xffb{h\x03\xff\xffC\x1aFO\xff\x00\x03\xffb{h\x03\xff\xffC\x1aFO\xff~S\x13c{h\x03\xff\xffC\x1aFO\xff\x00\x03Sc{h\x03\xff\xffC\x1aFO\xff\x00\x03\xffc\x00\xff\x00\xff(7\xffF\xff\xff\xff\xff\x00\xff\xff\xff\x00\xff\xff9\xff\xffB.\xff?\xff\xff\xff\xff\x00\xff\xff`\xff`z`\x00}\x03{a\xff\xff{i[\x00\xffh\x13D\xff\xff\x000\x07\xff\xff:\xff\xff\xffz\xff\xffSzg\xff\xffz\xff\xff\x04z{h\x03\xff\xffC[izh\x02\xff\xffB\xffa{h\x03\xff\xffC\x1bizh\x02\xff\xffBSa{h\x03\xff\xffC\x1aF;i\x13a{i\x00+\x1d\xff{h\x03\xff\xffC\xffizh\x02\xff\xffB\x13bzio\xff\x00C\x13D[\x00\xffh\x13D\xff\xff\x000\x07\xff\xff:\xff\xff\xffz\xff\xff9zg\xff\xffz{h\x03\xff\xffC\xff\xff\x07z{h\x03\xff\xffC\xff\xff\x07z\xff\xffgz{h\x03\xff\xffC\xff\xff\x0dz'\xff'z{h\x03\xff\xffC\xff\xff\x08j{h\x03\xff\xffC\xff\xff\x0ezf\xff\xffz7\xffgz{h\x03\xff\xffC\xff\xff\x04j{h\x03\xff\xffC\xff\xff\x09zf\xff\xffz7\xff'z{h\x03\xff\xffC\xff\xff\x05j{h\x03\xff\xffC\xff\xff\x0azf\xff\xffz7\xff'z{h\x03\xff\xffC\xff\xff\x06j{h\x03\xff\xffC\xff\xff\x0bzf\xff\xffzw\xff'j{h\x03\xff\xffC\xff\xff\x0cz\xff\xff\xffz\xff\xff\x0fzg\xff\xffz{i[\x00\xffh\x13D\xff\xff\xffz\x17\xff\xff}\x0a\x12\xff\x1a\xff{i\x013{a{i\xff\xff\x00o\xff\xffV\xff\x00\xff\x00\xff\x1c7\xffF]\xff\x04{pG\x00\x00\x008\x00\x00\x00G\xff\xff\xff\xff\x00\xffx`O\xff`C\xff\xff\xff>\x03\xff\x01\x03\x00+\x13\xffO\xff`C\xff\xff\x00>\x03\xff\x01\x03\x00+\x0b\xff\x00\xff\x00\xffO\xff`C\x1bh\x00+\xff\xffO\xff`Czh\xff\xff\x1ap{h\x18F\x0c7\xffF]\xff\x04{pG\xff\xff\xff\xff\x00\xff\xff`\xff`z`\x00}\x03{a\x00}\x03{a\x09\xff\xffhZ\x1c\xff`\x1bx\x18F\xff\xff\xff\xff{i\x013{azi{h\xffB\xff\xff{h\x18F\x187\xffF\xff\xff\x00\x00\xff\xff\xff\xff\x00\xffx`{h\x1bh(J\xffBJ\xff(K(J\x1a`(K)J\x1a`)K\x03\xff\xffC\xff\xffT0\x00+5\xff%K\x03\xff\xffC\xffk}\x03J\x02\xff\xffBSb!K\x03\xff\xffC\x1bl\x1fJ\x02\xff\xffB\xffb\x1dK\x03\xff\xffC[l\x1bJ\x02\xff\xffB\xffb\x19K\x03\xff\xffC\xffl\x17J\x02\xff\xffB\x13c\x15K\x03\xff\xffC\xffl\x13J\x02\xff\xffBSc\x11K\x03\xff\xffC\x1bm\x0fJ\x02\xff\xffB\xffc\x0dK\x03\xff\xffC\x00"\xff\xffT \x06K\x1bh\x07J\x11h\x08J\x18F\xff\xff\xff\xff\x00\xff\x087\xffF\xff\xff\x04X\x01@\xff\xff\x00 \xffF\x00 \xff\xff\x00 \xfff\x00 ,\x06\x00 \xff\xff\xff\xff\x00\xffx`{h\x1bh\x0aJ\xffB\x0d\xff\x0aK\x0aJ\x1a`\x0aK\x0bJ\x1a`\x07K\x1bh\x08J\x11h\x09J\x18F\xff\xff\xff\xff\x00\xff\x087\xffF\xff\xff\x00\xff\x04X\x01@\xff\xff\x00 \xffV\x00 \xff\xff\x00 \xffv\x00 ,\x06\x00 \xff\xff\x00\xff\x00!8H\xff\xff}\x0a\xff\x01\xffR\xff\x00\xff\xff\xff\x00\xff\xff\xff\x00\xff\xff\xff\x00\xff\xff\xff\x00\xff\xff\xff\x00\xff\xff\xff\x00\xffB\xff\x00\xff\x0a\xff\x00\xff@\xff\x00\xff\xff\xff\x00\xff&\xff\x00\xff\xff\xff\x00\xffb\xff\x00\xff\xff\xff\x06\xff\xff\xffO\xff\x00a&H\x02\xff\xff\xffO\xff\xffR%I%H\x04\xff\xff\xffO\xff\xffR}\x04I}\x04H\x04\xff\xff\xff}\x04H\x05\xff\x04\xff<!}\x03H\x06\xff\x1e\xff<!"H\x06\xff\x1a\xff<!!H\x06\xff\x16\xff\x16K\x1bh\x18F\xff\xff\xff\xff\x10\xff\xff\xff\x00}\x03\xff\xff\x0e\xff\x02F\x0bF\x10F\x19F\x0d\xff\xff\xff\x00}\x03\xff\xff\xff\xff\x02F\x0bF\x16L\x10F\x19F\xff\xff\xff\xff\x03Fcb\x12K[j\xff\xff\x12K\x1a\xff\x06\xff\xff\xff\xff\xff\xff\xff\x00\xff\x00\x00\x00\x00\x00\xff\xff@\x00\x00\x00\x00\x00\xff]@,\x06\x00 \x00\x14\x02@\xffF\x00 \x18\x02\x00 \xfff\x00 \xff\x02\x00 \xff\x05\x00 \xff\x04\x00 <\x05\x00 \xff\x05\x00 \x00\x00\x01@\xff\xff\x00 \xff\xff\xff\xff\x00\xff\x07\xff \x030"\x00!\x18F!\xff\xff\xff\x07\xff\x0c\x03\x00"\x1a`Z`\xff`\xff`\x1aa+K\x1bl}\x0aJC\xff\xffS\x13d(K\x1bl\x03\xff\xffS\xff`\xffh&K\x1bh}\x03\xff@C}\x04JC\xff\xffC\x13`"K\x1bh\x03\xff@C{`{h\x01}\x03;bO\xff\xff3{b\x02}\x03\xffcO\xff\xff\x03\xffc\x08}\x03;dl}\x03{d\x02}\x03\xffd\x02}\x03\xffd\x07\xff \x03\x18F\x03\xff\xff\xff\x03F\x00+\x01\xff\x00\xfft\xff\x03\xffz\xff\x03F\x00+\x01\xff\x00\xffm\xff\x0f}\x03\xff`\x02}\x03;a\x00}\x03{aO\xff\xffS\xffa\x00}\x03\xffa\x07\xff\x0c\x03\x03!\x18F\x03\xffX\xff\x03F\x00+\x01\xff\x00\xffW\xff\x00\xffP7\xffF\xff\xff\x00\xff\x008\x02@\x00p\x00@\xff\xff\xff\xff\x00\xff;\x1d\xff"\x00!\x18F!\xff.\xffO\xff\x00}\x03{`b}\x03\xffa\x02}\x03;b\x02}\x03\xffa\x00}\x03{b\x01}\x03\xffb\x00}\x03;c\x00}\x03;d;\x1d\x18F\x03\xff\x1c\xff\x03F\x00+\x01\xff\x00\xff+\xff\x00\xff\xff7\xffF\xff\xff\x00\x00\xff\xff\x00\xff\x0dK\x0eJ\x1a`\x0cK\x00"\x1aq\x0aK\x00"Zq\x09K\x00"Za\x07K\x00"\xffa\x06K\x01"\x1ab\x04H\x01\xff\xff\xff\x03F\x00+\x01\xff\x00\xff\x0a\xff\x00\xff\xff\xffL\x01\x00 \x000\x02@\xff\xff\x00\xff\x1bK\x1cJ\x1a`\x1aK\x1bJZ`\x18K\x00"\xff`\x17K\x01"\xff`\x15K\x00"\x1aa\x14K\x00"Za\x12K\x00"\xffa\x11K\x00"\xffa\x0fK\x00"\x1ab\x0eH\x02\xff\xff\xff\x03F\x00+\x01\xff\x00\xff\xff\xff\x00!\x09H\x03\xffK\xff\x03F\x00+\x01\xff\x00\xff\xff\xff\x00!\x05H\x03\xff\xff\xff\x03F\x00+\x01\xff\x00\xff\xff\xff\x00\xff\xff\xff\x00\xffp\x01\x00 \x00T\x00@\x0d\x03\x00`\xff\xff\x00\xff\x1bK\x1cJ\x1a`\x1aK\x1bJZ`\x18K\x00"\xff`\x17K\x01"\xff`\x15K\x00"\x1aa\x14K\x00"Za\x12K\x00"\xffa\x11K\x00"\xffa\x0fK\x00"\x1ab\x0eH\x02\xff\xff\xff\x03F\x00+\x01\xff\x00\xff\xff\xff\x00!\x09H\x03\xff\x0b\xff\x03F\x00+\x01\xff\x00\xff\xff\xff\x00!\x05H\x03\xffM\xff\x03F\x00+\x01\xff\x00\xff\xff\xff\x00\xff\xff\xff\x00\xff\xff\x01\x00 \x00X\x00@hG@ \xff\xff\x00\xff&K'J\x1a`%K\x03"Z`}\x03K\x00"\xff`"K\x00"\x1aa K\x00"\xffa\x1fK\x00"\xff`\x1dK\x00"Zb\x1cK\x00"\xffb\x1aK\x00"\xffb\x02}\x03\x00"\x00!\x17H\x04\xff{\xff\x03F\x00+\x01\xff\x00\xff\\\xff\x15K\x16J\x1a`\x14K\x02"Z`\x12K\x01"\xff`\x11K\x00"\x1aa\x0fK\x00"\xffa\x0eK\x00"\xff`\x0cK\x00"Zb\x0bK\x00"\xffb\x09K\x00"\xffb\x02}\x03\x00"\x00!\x06H\x04\xffU\xff\x03F\x00+\x01\xff\x00\xff6\xff\x00\xff\xff\xff\x18\x02\x00 \x04X\x01@\xff\x02\x00 }\x04X\x01@\xff\xff\x00\xff\x1bK\x1cJ\x1a`\x1aKO\xff\xffrZ`\x18K\x00"\xff`\x16KO\xff\xffb\xff`\x14K\x00"\x1aa\x13K\x00"Za\x11KO\xff\xff"\xffa\x0fK\x00"\xffa\x0eK\x00"\x1ab\x0cK\x00"Zb\x0bK\x00"\xffb\x09K\x07"\xffb\x08K\x00"\x1ac\x06K\x08"Zc\x05H\x04\xffm\xff\x03F\x00+\x01\xff\x00\xff\xff\xff\x00\xff\xff\xff\x00\xff\xff\x03\x00 \x00P\x01@\xff\xff\xff\xff\x00\xff\x07\xff\x0c\x03}\x04"\x00!\x18F!\xff\xff\xff;F\x00"\x1a`Z`\xff`}\x03K}\x03J\x1a`!K\x00"Z` K\x00"\xff`\x1eKw"\xff`\x1dK\x00"\x1aa\x1bK\x00"Za\x1aK\xff"\xffa\x03}\x03\xff`\x00}\x03;a\x01}\x03{a\x00}\x03\xffa\x0a}\x03\xffa\x00}\x03;b\x01}\x03{b\x00}\x03\xffb\x0a}\x03\xffb\x07\xff\x0c\x03\x19F\x0eH\x05\xff \xff\x03F\x00+\x01\xff\x00\xff\xff\xff\x00}\x03;`\x00}\x03{`\x00}\x03\xff`;F\x19F\x06H\x06\xff\xff\xff\x03F\x00+\x01\xff\x00\xff\xff\xff\x00\xff07\xffF\xff\xff\x00\xff\xff\x04\x00 \x00\x00\x01@\xff\xff\xff\xff\x00\xff\x07\xff\x10\x03\x00"\x1a`Z`\xff`\xff`;\x1d\x00"\x1a`Z`\xff`\x1fKO\xff\xffB\x1a`\x1dKk"Z`\x1bK\x00"\xff`\x1aKD\xff\x1a\x12\xff`\x18K\x00"\x1aa\x16K\x00"\xffa\x15H\x05\xff\x0c\xff\x03F\x00+\x01\xff\x00\xffi\xffO\xff\xffS;a\x07\xff\x10\x03\x19F\x0eH\x05\xff"\xff\x03F\x00+\x01\xff\x00\xff[\xff\x00}\x03{`\x00}\x03\xff`;\x1d\x19F\x07H\x06\xfff\xff\x03F\x00+\x01\xff\x00\xffM\xff\x03H\x05\xff@\xff\x00\xff 7\xffF\xff\xff\xff\x04\x00 \xff\xff\xff\xff\x00\xff\x07\xff\x0c\x03}\x04"\x00!\x18F!\xff}\x03\xff;F\x00"\x1a`Z`\xff` K J\x1a`\x1eK\x00"Z`\x1dK\x00"\xff`\x1bKw"\xff`\x1aK\x00"\x1aa\x18K\xff"\xffa\x03}\x03\xff`\x00}\x03;a\x01}\x03{a\x00}\x03\xffa\x0a}\x03\xffa\x00}\x03;b\x01}\x03{b\x00}\x03\xffb\x0a}\x03\xffb\x07\xff\x0c\x03\x19F\x0cH\x05\xffy\xff\x03F\x00+\x01\xff\x00\xff\x06\xff\x00}\x03;`\x00}\x03\xff`;F\x19F\x05H\x06\xff\x11\xff\x03F\x00+\x01\xff\x00\xff\xff\xff\x00\xff07\xffF\xff\xff<\x05\x00 \x00\x04\x00@\xff\xff\xff\xff\x00\xff\x07\xff\x0c\x03}\x04"\x00!\x18F \xff\xff\xff;F\x00"\x1a`Z`\xff` K J\x1a`\x1eK\x00"Z`\x1dK\x00"\xff`\x1bKw"\xff`\x1aK\x00"\x1aa\x18K\xff"\xffa\x03}\x03\xff`\x00}\x03;a\x01}\x03{a\x00}\x03\xffa\x0a}\x03\xffa\x00}\x03;b\x01}\x03{b\x00}\x03\xffb\x0a}\x03\xffb\x07\xff\x0c\x03\x19F\x0cH\x05\xff%\xff\x03F\x00+\x01\xff\x00\xff\xff\xff\x00}\x03;`\x00}\x03\xff`;F\x19F\x05H\x06\xff\xff\xff\x03F\x00+\x01\xff\x00\xff\xff\xff\x00\xff07\xffF\xff\xff\xff\x05\x00 \x00\x08\x00@\xff\xff\x00\xff\x0eK\x0fJ\x1a`\x0dK\x00"Z`\x0bK\x00"\xff`\x0aKO\xff\xffb\xff`\x08K\x00"\x1aa\x06K\xff"\xffa\x05H\x05\xff"\xff\x03F\x00+\x01\xff\x00\xff\x7f\xff\x00\xff\xff\xff\x00\xff\xff\x05\x00 \x00 \x00@\xff\xff\xff\xff\x00\xff\x14K\x1bk\x13JC\xff\xff\x03\x13c\x11K\x1bk\x03\xff\xff\x03{`{h\x00"\x00!9 \x01\xff\xff\xff9 \x01\xff\xff\xff\x00"\x00!< \x01\xff\xff\xff< \x01\xff\xff\xff\x00"\x00!D \x01\xff\xff\xffD \x01\xff\xff\xff\x00\xff\x087\xffF\xff\xff\x00\xff\x008\x02@\xff\xff\xff\xff\x00\xff\x07\xff\x1c\x03\x00"\x1a`Z`\xff`\xff`\x1aaXK\x1bkWJC\xff\x10\x03\x13cUK\x1bk\x03\xff\x10\x03\xffa\xffiRK\x1bkQJC\xff \x03\x13cOK\x1bk\x03\xff \x03{a{iLK\x1bkKJC\xff\xff\x03\x13cIK\x1bk\x03\xff\xff\x03;a;iFK\x1bkEJC\xff\x04\x03\x13cCK\x1bk\x03\xff\x04\x03\xff`\xffh@K\x1bk?JC\xff\x01\x03\x13c=K\x1bk\x03\xff\x01\x03\xff`\xffh:K\x1bk9JC\xff\x08\x03\x13c7K\x1bk\x03\xff\x08\x03{`{h4K\x1bk3JC\xff\x02\x03\x13c1K\x1bk\x03\xff\x02\x03;`;h\x00"\x08!.H\x01\xff\xff\xff\x00"O\xff\xffA,H\x01\xff\xff\xff\x00"O\xff\xffq}\x0aH\x01\xff\xff\xff\x0c}\x03\xffa\x00}\x03;b\x00}\x03{b\x07\xff\x1c\x03\x19F}\x03H\x01\xff\xff\xff\x08}\x03\xffa\x02}\x03;b\x00}\x03{b\x03}\x03\xffb\x05}\x03\xffb\x07\xff\x1c\x03\x19F\x1cH\x01\xff\xff\xff\x08}\x03\xffa\x01}\x03;b\x00}\x03{b\x00}\x03\xffb\x07\xff\x1c\x03\x19F\x13H\x01\xff\xff\xffO\xff\xffC\xffa\x01}\x03;b\x00}\x03{b\x00}\x03\xffb\x07\xff\x1c\x03\x19F\x0cH\x01\xff\xff\xffO\xff\xffs\xffa\x01}\x03;b\x00}\x03{b\x00}\x03\xffb\x07\xff\x1c\x03\x19F\x06H\x01\xffv\xff\x00\xff07\xffF\xff\xff\x008\x02@\x00\x00\x02@\x00\x14\x02@\x00\x08\x02@\xff\xff\xff\xff\x00\xffx`\x11K\x1bh\x00+\x07\xff{h\xff\xff\xff?\x03\xff\x0dK\x02"\x1a`\x11\xff\x0bK\x1bh\x02+\x06\xff{h\x01+\x03\xff\x08K\x00"\x1a`\x06\xff\x06K\x1ah{h\x13D\x04J\x13`\x00\xff\x00\xff\x0c7\xffF]\xff\x04{pG \x06\x00 \xff\xff\xff\xff\x00\xffx`{h\x1bh\xff\xff\xffO\x01\xff\x0a\xff\xff\xff{h}\x03J\xffB@\xff\x04!"H\x01\xff\xff\xff\x03F\x01+\x19\xff K\x1bh\x013\x1fJ\x13`\x1eK\x1ah\x1eK\x1bh\xffB\x0e\xff\x02\xff\x1aK\x00"\x1a`\x04!\x17H\x01\xff\xff\xff\x03F\x01+\xff\xffO\xff\xff0\xff\xff\xff\xff\x08!\x12H\x01\xff\xff\xff\x03F\x01+\x18\xff\x10K[h\x013\x0eJS`\x0dKZh\x0dK\x1bh\xffB\x0d\xff\x02\xff\x0aK\x00"Z`\x08!\x07H\x01\xff\xff\xff\x03F\x01+\xff\xff\x01 \xff\xff\xff\xff\x00\xff\x087\xffF\xff\xff\xff\x05\x00 \x00\x14\x02@}\x04\x06\x00 \x04\x00\x00 \xff\xff\x00\xffr\xff\x00\xff\xff\xff\x00\x00\xff\xff\xff\xff\x00\xff\x12K\x1bl\x11JC\xff\xffS\x13d\x0fK\x1bl\x03\xff\xffS{`{h\x0cK[l\x0bJC\xff\xffCSd\x09K[l\x03\xff\xffC;`;h\x00"\x00!\x05 \x00\xff%\xff\x05 \x00\xff>\xff\x00\xff\x087\xffF\xff\xff\x00\xff\x008\x02@\xff\xff\xff\xff\x00\xffx`{h\x1bh\x0aJ\xffB\x0b\xff\x0aK\x1bk\x09JC\xff\xffS\x13c\x07K\x1bk\x03\xff\xffS\xff`\xffh\x00\xff\x147\xffF]\xff\x04{pG\x00\xff\x000\x02@\x008\x02@\xff\xff\xff\xff\x00\xffx`\x07\xff\xff\x03\x00"\x1a`Z`\xff`\xff`\x1aa\x07\xff\x18\x03\xff"\x00!\x18F \xff\xff\xff{h\x1bhCJ\xffB<\xffO\xff\xffC\xffa\x00}\x03\xffg\x07\xff\x18\x03\x18F\x03\xffz\xff\x03F\x00+\x01\xff\xff\xff\xff\xff;K\x1bk:JC\xff\x02\x03\x13c8K\x1bk\x03\xff\x02\x03{a{i\xff}\x03\xff\xff\xff0\x12}\x03\xff\xff\xff0\x01}\x03\xff\xff\xff0\x03}\x03\xff\xff\xff0\x04}\x03\xff\xff\xff0\x07\xff\xff\x03\x19F-H\x01\xffL\xff}\x0aK\x1bl)JC\xff\x00\x13\x13d'K\x1bl\x03\xff\x00\x13;a;iA\xff{h\x1bh%J\xffB<\xffO\xff\x00C\xffa\x00}\x03\xff\xff\xff0\x07\xff\x18\x03\x18F\x03\xff7\xff\x03F\x00+\x01\xff\xff\xffF\xff\x19K\x1bk\x18JC\xff \x03\x13c\x16K\x1bk\x03\xff \x03\xff`\xffh\x03}\x03\xff\xff\xff0\x12}\x03\xff\xff\xff0\x01}\x03\xff\xff\xff0\x03}\x03\xff\xff\xff0\x04}\x03\xff\xff\xff0\x07\xff\xff\x03\x19F\x0dH\x01\xff\x09\xff\x09K\x1bl\x08JC\xff\xff\x03\x13d\x06K\x1bl\x03\xff\xff\x03\xff`\xffh\x00\xff\xff7\xffF\xff\xff\x00\xff\x00T\x00@\x008\x02@\x00\x04\x02@\x00X\x00@\x00\x14\x02@\xff\xff\xff\xff\x00\xffx`{h\x1bh\x14J\xffB\x0e\xff\x14K\x1bl\x13J}\x03\xff\x00\x13\x13d@!\x11H\x01\xff\xff\xff\xff!\x0fH\x01\xff\xff\xff\x12\xff{h\x1bh\x0dJ\xffB\x0d\xff\x0aK\x1bl\x09J}\x03\xff\xff\x03\x13d\x01!\x09H\x01\xffs\xff\x02!\x07H\x01\xffo\xff\x00\xff\x087\xffF\xff\xff\x00\xff\x00T\x00@\x008\x02@\x00\x04\x02@\x00X\x00@\x00\x14\x02@\xff\xff\xff\xff\x00\xffx`\x07\xff\x14\x03\x00"\x1a`Z`\xff`\xff`\x1aa{h\x1bh3J\xffB_\xff3K[l2JC\xff\xff\x13Sd0K[l\x03\xff\xff\x13;a;i-K\x1bk,JC\xff \x03\x13c}\x0aK\x1bk\x03\xff \x03\xff`\xffhO\xff0s{a\x02}\x03\xffa\x00}\x03\xffa\x03}\x03;b\x05}\x03{b\x07\xff\x14\x03\x19F!H\x01\xffz\xff K!J\x1a`\x1fKO\xff\xffbZ`\x1dK@"\xff`\x1bK\x00"\xff`\x1aKO\xff\xffb\x1aa\x18K\x00"Za\x16K\x00"\xffa\x15K\x00"\xffa\x13K\x00"\x1ab\x12K\x04"Zb\x10K\x03"\xffb\x0fK\x00"\xffb\x0dK\x00"\x1ac\x0cH\x00\xff\xff\xff\x03F\x00+\x01\xff\xff\xffe\xff{h\x07JZe\x06J{h\xffc\x00\xff(7\xffF\xff\xff\x00\xff\x00P\x01@\x008\x02@\x00\x14\x02@D\x04\x00 pd\x02@\xff\xff\xff\xff\x00\xffx`\x07\xff}\x04\x03\x00"\x1a`Z`\xff`\xff`\x1aa{h\x1bhTJ\xffB)\xffTK[lSJC\xff\x01\x03SdQK[l\x03\xff\x01\x03;b;jNK\x1bkMJC\xff\x10\x03\x13cKK\x1bk\x03\xff\x10\x03\xffa\xffiO\xff c{b\x02}\x03\xffb\x00}\x03\xffb\x00}\x03;c\x01}\x03{c\x07\xff}\x04\x03\x19FBH\x01\xff\xff\xffw\xff{h\x1bh@J\xffBD\xff<K\x1bl;JC\xff\x02\x03\x13d9K\x1bl\x03\xff\x02\x03\xffa\xffi6K\x1bk5JC\xff\x01\x03\x13c3K\x1bk\x03\xff\x01\x03{a{i0K\x1bk/JC\xff\x04\x03\x13c-K\x1bk\x03\xff\x04\x03;a;i@}\x03{b\x02}\x03\xffb\x00}\x03\xffb\x00}\x03;c\x02}\x03{c\x07\xff}\x04\x03\x19F'H\x01\xff\xff\xff\xff}\x03{b\x02}\x03\xffb\x00}\x03\xffb\x00}\x03;c\x02}\x03{c\x07\xff}\x04\x03\x19F H\x01\xff\xff\xff-\xff{h\x1bh\x1eJ\xffB(\xff\x17K\x1bl\x16JC\xff\x04\x03\x13d\x14K\x1bl\x03\xff\x04\x03\xff`\xffh\x11K\x1bk\x10JC\xff\x08\x03\x13c\x0eK\x1bk\x03\xff\x08\x03\xff`\xffhO\xff@S{b\x02}\x03\xffb\x00}\x03\xffb\x00}\x03;c\x02}\x03{c\x07\xff}\x04\x03\x19F\x0aH\x01\xff\xff\xff\x00\xff87\xffF\xff\xff\x00\xff\x00\x00\x01@\x008\x02@\x00\x10\x02@\x00\x04\x00@\x00\x00\x02@\x00\x08\x02@\x00\x08\x00@\x00\x0c\x02@\xff\xff\xff\xff\x00\xffx`{h\x1bh\xff\xff\xffO\x14\xff\x19K\x1bl\x18JC\xff\x01\x03\x13d\x16K\x1bl\x03\xff\x01\x03\xff`\xffh\x00"\x00!\x1c \x00\xff\xff\xff\x1c \x00\xff\xff\xff\x18\xff{h\x1bh\x0eJ\xffB\x13\xff\x0cK\x1bl\x0bJC\xff\xffs\x13d\x09K\x1bl\x03\xff\xffs\xff`\xffh\x00"\x00!- \x00\xff\xff\xff- \x00\xff\xff\xff\x00\xff\x107\xffF\xff\xff\x00\xff\x008\x02@\x00 \x00@\xff\xff\xff\xff\x00\xffx`{h\x1bhaJ\xffB[\xffaK\x1bh\x00+\x0b\xff`K[l_JC\xff\xff\x03Sd]K[l\x03\xff\xff\x03;a;iYK\x1bh\x013WJ\x13`p}\x03{a\x02}\x03\xffa\x00}\x03\xffa\x00}\x03;b\x06}\x03{b\x07\xff\x14\x03\x19FRH\x01\xff\xff\xffQKRJ\x1a`PK\x00"Z`NK\x00"\xff`MK\x00"\xff`KKO\xff\xffb\x1aaIKO\xff\x00bZaGKO\xff\x00R\xffaEKO\xff\xffr\xffaCKO\xff@2\x1abAK\x00"Zb@H\x00\xff`\xff\x03F\x00+\x01\xff\xff\xff\xff\xff{h;J\x1ag:J{h\xffc{h8J\xfff7J{h\xffc{h\x1bh7J\xffB[\xff0K\x1bh\x00+\x0b\xff/K[l.JC\xff\xff\x03Sd,K[l\x03\xff\xff\x03\xff`\xffh(K\x1bh\x013'J\x13`\x08}\x03{a\x02}\x03\xffa\x00}\x03\xffa\x00}\x03;b\x06}\x03{b\x07\xff\x14\x03\x19F!H\x01\xff\xff\xff}\x04K}\x04J\x1a`"K\x00"Z`!K@"\xff`\x1fK\x00"\xff`\x1eKO\xff\xffb\x1aa\x1cKO\xff\x00bZa\x1aKO\xff\x00R\xffa\x18KO\xff\xffr\xffa\x16KO\xff@2\x1ab\x14K\x00"Zb\x12H\x00\xff\xff\xff\x03F\x00+\x01\xff\xff\xff\xff\xff{h\x0eJ\x1ag\x0dJ{h\xffc{h\x0bJ\xfff\x0aJ{h\xffc\x00\xff(7\xffF\xff\xff\x04X\x01@\xff\xff\x00 \x008\x02@\x00\x10\x02@ \x03\x00 (d\x02@}\x04X\x01@\xff\x03\x00 \xffd\x02@\xff\xff\x00\xff\xff\xff\xff\xff\x00\xff\xff\xff\xff\xff\x00\xff\xff\xff\xff\xff\x00\xff\xff\xff\xff\xff\x00\xff\xff\xff\xff\xff\x00\xff\x00\xff\xffF]\xff\x04{pG\xff\xff\x00\xff\x00\xff\xffF]\xff\x04{pG\xff\xff\x00\xff\x00\xff\xffF]\xff\x04{pG\xff\xff\x00\xff\x00\xff\xff\xff\x00\xff\xff\xff\xff\xff\x00\xff\x00\xff\xffF]\xff\x04{pG\x00\x00\xff\xff\x00\xff\x02H\x04\xff\xff\xff\x00\xff\xff\xff\x00\xff\xff\x04\x00 \xff\xff\x00\xff\x02H\x04\xff\xff\xff\x00\xff\xff\xff\x00\xff\xff\x05\x00 \xff\xff\x00\xff\x02H\x00\xff\xff\xff\x00\xff\xff\xff\x00\xff \x03\x00 \xff\xff\x00\xff\x02H\x00\xff\xff\xff\x00\xff\xff\xff\x00\xffD\x04\x00 \xff\xff\x00\xff\x02H\x00\xff\xff\xff\x00\xff\xff\xff\x00\xff\xff\x03\x00 \xff\xff\x00\xff\x01}\x03\x18F\xffF]\xff\x04{pG\xff\xff\xff\xff\x00\xffx`9` \xff\xff\xff\x03F\x16"\x1a`O\xff\xff3\x18F\x087\xffF\xff\xff\xff\xff\xff\xff\x00\xffx`O\xff\xff1xh\xff\xff\xff\xff\xff\xff\xff\xff\xff\xff\x00\xff\xff`\xff`z`\x00}\x03{a\x0a\xff\xff\xff\x00\xff\x01F\xffhZ\x1c\xff`\xff\xff\x1ap{i\x013{azi{h\xffB\xff\xff{h\x18F\x187\xffF\xff\xff\xff\xff\xff\xff\x00\xffx`O\xff\xff3\x18F\x0c7\xffF]\xff\x04{pG\xff\xff\xff\xff\x00\xffx`9`;hO\xff\x00RZ`\x00}\x03\x18F\x0c7\xffF]\xff\x04{pG\xff\xff\xff\xff\x00\xffx`\x01}\x03\x18F\x0c7\xffF]\xff\x04{pG\xff\xff\xff\xff\x00\xff\xff`\xff`z`\x00}\x03\x18F\x147\xffF]\xff\x04{pG\x00\x00\xff\xff\xff\xff\x00\xffx`\x14J\x15K\xff\x1a{a{i;a\x13K\x1bh\x00+\x02\xff\x11K\x12J\x1a`\x10K\x1ah{h\x13D:i\xffB\x07\xff \xff\x06\xff\x03F\x0c"\x1a`O\xff\xff3\x09\xff\x08K\x1bh\xff`\x07K\x1ah{h\x13D\x05J\x13`\xffh\x18F\x187\xffF\xff\xff\x00\x00\x05 \x00\x04\x00\x00\xff\xff\x00 \xff\xff\x00 \xff\xff\x00\xff\x06K\xff\xff\xff0\x05JC\xffp\x03\xff\xff\xff0\x00\xff\xffF]\xff\x04{pG\x00\xff\x00\xff\x00\xff\xff\xff4\xff\x0dH\x0eI\x0eJ\x00}\x03\x02\xff\xffX\xffP\x043\xff\x18\xffB\xff\xff\x0bJ\x0bL\x00}\x03\x01\xff\x13`\x042\xffB\xff\xff\xff\xff\xff\xff \xff\xff\xff\xff\xff\xff\xffpG\x00\x00\x05 \x00\x00\x00 0\x01\x00 @a\x02\x080\x01\x00 \xff\xff\x00 \xff\xff\x00\x00\xff\xff\xff\xff\x00\xff\x03F\xff\xff\xff\xff\x18F\x00\xff\x09\xff\x03F\xffs\xff{\xff+\x0c\xff\x00 \x00\xff\x01\xff\x03F\xffs\xff{\x01+\x04\xff\xff{\xff\xff\xff\xff\x03J\xffT\x00\xff\x107\xffF\xff\xff\x00\xff\xff\xff\x00 \xff\xff\xff\xff\x00\xff\x03F\xff\xff\x00\xff\x0c7\xffF]\xff\x04{pG\xff\xff\xff\xff\x00\xff\x03F\xff\xff\xff\xff\xff\xff\xff!\x18F\x08\xffL\xff\x03F\xff\xff\x18F\x087\xffF\xff\xff\xff\xff\xff\xff\x00\xff\x03F\xff\xff\xff\xff\x18F\x00\xff\xff\xff\xff\xff\x18F\x00\xff\xff\xff\x00\xff\x087\xffF\xff\xff\x00\x00\xff\xff\xff\xff\x00\xff\x03F\xff\xff\x00}\x03\xffs\xff\xff\xff\xff\x02!\x18F\x08\xff'\xff\x03F\xffs\xff{\xff\xff\x03\xff\x0f\x03\xff\xff\xffs\xff{\xff\xff\x02+\x01\xff\x00}\x03\xffs\xff{\xff\xff\x05KZp\x04K\x00"\xffp\xff{\xff\xff\x18F\x107\xffF\xff\xff\xff\xff\x00 \xff\xff\xff\xff\x00\xff\x03F\xff`z`\xff\xff\x00}\x03\xffu\x1fK\xffx\x1eK[x\xffB4\xff\x1cK\xffx\x00+\x02\xff\x01+\x03\xff\x05\xff\x03}\x03\xffu\x02\xff\x09}\x03\xffu\x00\xff\xff\xff\xff\xff\x07\xff\x10\x02\xff}]\x04}\x03\x07\xff\xff\xff;|\x1b\x02\x1b\xff\x03\xffpc\x1a\xff{|\x1b\xff\x13C\x1b\xff\xff\xff\xffh\x1a\xff\xff|\x1b\x02\x1b\xff\x03\xffpc\x1a\xff\xff|\x1b\xff\x13C\x1b\xff\xff\xff{h\x1a\xff\x04K\xffx\x013\xff\xff\x02K\xffp\x00\xff\x187\xffF\xff\xff\xff\xff\x00 \xff\xff\xff\xff\x00\xff\x03F\xff\xff\x00}\x03\xffs\x01}\x03\xffs\xff\xff\xff\xff\xff{\xff!\x18F\x07\xffv\xff\x00\xff\x107\xffF\xff\xff\xff\xff\xff\xff\x00\xff\x03F\xff\xff\x00}\x03\xffs\x00}\x03\xffs\xff\xff\xff\xff\xff{\xff!\x18F\x07\xffb\xff\x00\xff\x107\xffF\xff\xff\xff\xff\xff\xff\x00\xff\x03F\xff\xff\x00}\x03\x18F\x0c7\xffF]\xff\x04{pG\xff\xff\xff\xff\x00\xff\x03F\xff\xff\x00\xff\x0c7\xffF]\xff\x04{pG\xff\xff\xff\xff\x00\xff\x03F\xff\xff\x00}\x03\xff`\xffh\x18F\x147\xffF]\xff\x04{pG\x00\x00\xff\xff\xff\xff\x00\xff\x03F\xff\xff\x00}\x03\xffs\x00}\x03\xffs\x0b\xff\xff{\x0aJ\xff\\\xff\xff\xff\xff\xffB\x01\xff\xff{\x06\xff\xff{\x013\xffs\xff{\x01+\xff\xff\xff}\x03\x18F\x147\xffF]\xff\x04{pG\xff\xff\x00 \xff\xff\x00\xff\x03 \x00\xff)\xff\x0f \x00\xff\x06\xff\xff\xff\xff\xff\x00}\x03\x18F\xff\xff\x00\x00\xff\xff\xff\xff\x00\xffx`\x12K\x1ah\x12K\x1bx\x19FO\xffzs\xff\xff\xff\xff\xff\xff\xff\xff\x18F\x00\xffC\xff\x03F\x00+\x01\xff\x01}\x03\x0e\xff{h\x0f+\x0a\xff\x00"yhO\xff\xff0\x00\xff\x0b\xff\x06J{h\x13`\x00}\x03\x00\xff\x01}\x03\x18F\x087\xffF\xff\xff\x08\x00\x00 8\x00\x00 4\x00\x00 \xff\xff\x00\xff\x06K\x1bx\x1aF\x06K\x1bh\x13D\x04J\x13`\x00\xff\xffF]\xff\x04{pG\x00\xff8\x00\x00 \xff\xff\x00 \xff\xff\x00\xff\x03K\x1bh\x18F\xffF]\xff\x04{pG\x00\xff\xff\xff\x00 \xff\xff\xff\xff\x00\xffx`{h\x03\xff\x07\x03\xff`\x0bK\xffh\xff`\xffhO\xff\xff\x03\x13@\xff`\xffh\x1a\x02\xffh\x1aC\x06K\x13C\xff`\x04J\xffh\xff`\x00\xff\x147\xffF]\xff\x04{pG\x00\xff\x00\xff\x00\x00\xff\x05\xff\xff\x00\xff\x04K\xffh\x1b\x0a\x03\xff\x07\x03\x18F\xffF]\xff\x04{pG\x00\xff\x00\xff\xff\xff\xff\xff\x00\xff\x03F\xffq\xff\xff\x070\x00+\x0b\xff\xffy\x03\xff\x1f\x02\x07I\xff\xff\x070[\x09\x01 \x00\xff\x02\xffA\xff}\x03 \x00\xff\x0c7\xffF]\xff\x04{pG\x00\xff\x00\xff\x00\xff\xff\xff\xff\xff\x00\xff\x03F9`\xffq\xff\xff\x070\x00+\x0a\xff;h\xff\xff\x0cI\xff\xff\x070\x12\x01\xff\xff\x0bD\xff\xff\x00}\x03\x0a\xff;h\xff\xff\x08I\xffy\x03\xff\x0f\x03\x04;\x12\x01\xff\xff\x0bD\x1av\x00\xff\x0c7\xffF]\xff\x04{pG\x00\xff\x00\xff\x00\xff\x00\xff\xff\xff\xff\xff\x00\xff\xff`\xff`z`\xffh\x03\xff\x07\x03\xffa\xffi\xff\xff\x07\x03\x04+(\xff\x04}\x03\xffa\xffi\x043\x06+\x02\xff\xffi\x03;\x00\xff\x00}\x03{aO\xff\xff2\xffi\x02\xff\x03\xff\xffC\xffh\x1a@{i\xff@O\xff\xff1{i\x01\xff\x03\xff\xffC{h\x0b@\x13C\x18F}\x047\xffF]\xff\x04{pG\x00\x00\xff\xff\xff\xff\x00\xffx`{h\x01;\xff\xff\xff\x7f\x01\xff\x01}\x03\x0f\xff\x0aJ{h\x01;S`\x0f!O\xff\xff0\xff\xff\xff\xff\x05K\x00"\xff`\x04K\x07"\x1a`\x00}\x03\x18F\x087\xffF\xff\xff\x00\xff\x10\xff\x00\xff\xff\xff\xff\xff\x00\xffx`xh\xff\xff)\xff\x00\xff\x087\xffF\xff\xff\xff\xff\xff\xff\x00\xff\x03F\xff`z`\xffs\x00}\x03{a\xff\xff>\xffxazh\xffhxi\xff\xff\xff\xff\x02F\xff\xff\x0f0\x11F\x18F\xff\xff]\xff\x00\xff\x187\xffF\xff\xff\xff\xff\xff\xff\x00\xff\x03F\xffq\xff\xff\x070\x18F\xff\xff1\xff\x00\xff\x087\xffF\xff\xff\xff\xff\xff\xff\x00\xffx`xh\xff\xff\xff\xff\x03F\x18F\x087\xffF\xff\xff\x00\x00\xff\xff\xff\xff\x00\xffx`{h\x00+\x01\xff\x01}\x03T\xff{h[\x7f\xff\xff\x00+\x05\xff{h\x00"\x1awxh\xff\xff\xff\xff{h\x02"Zw{h\x1by\x00+\x0c\xff{h\x1bh"JZa{h\x1bh\xffh{h\x1bh"\xff\x18\x02\xff`\x0c\xff{h\xffh{h\xffh\x1aFxh\x00\xff4\xff\x03F\x00+\x01\xff\x01}\x03(\xff{h[y\x00+\x05\xff{h\x1bhO\xff\xff2\x1aa\x04\xff{h\x1bhzh\x12i\x1aa{h\x1bh\xffh}\x03\xff`\x01{hZi{h\x1bh\x0aC\xff`{h\x1bh\xffh}\x03\xff\xff\x01{h\xffi{h\x1bh\x0aC\xff`{h\x01"Zw\x00}\x03\x18F\x087\xffF\xff\xff\xff\x1d\xff\x04\xff\xff\xff\xff\x00\xff\xff`\xff`z`\x00}\x03\xffu\x1f}\x03;a\x00\xff;iZ\x1e:a\x00+\x09\xff;i\x03\xff\x1f\x03\xffh"\xff\x03\xff\x03\xff\x01\x03\x00+\xff\xff{h\x18+F\xff\x01\xffR\xff}\x03\xff\xff2\x00\x08\xff2\x00\x08\xff2\x00\x08\xff2\x00\x08\xff2\x00\x08\xff2\x00\x08\xff2\x00\x08\xff2\x00\x08\xff2\x00\x08\xff2\x00\x08\xff2\x00\x08\xff2\x00\x08\xff2\x00\x08\xff2\x00\x08\xff2\x00\x08\xff2\x00\x08\xff2\x00\x08\xff2\x00\x08\xff2\x00\x08\xff2\x00\x08\xff2\x00\x08\xff2\x00\x08\xff2\x00\x08\xff2\x00\x08\xff2\x00\x08;i\x06+\x13\xff\x01}\x03\xffu\x10\xff;i\x07+\x0f\xff\x01}\x03\xffu\x0c\xff;i\x0f+\x0b\xff\x01}\x03\xffu\x08\xff\x01}\x03\xffu\x06\xff\x00\xff\x04\xff\x00\xff\x02\xff\x00\xff\x00\xff\x00\xff\xff}]\x00+\x0d\xff\xffh\x1bh\xffhZa\xffh\x1bh\xffh}\x03\xff\x18\x01\xffh\x1bhzh\x0aC\xff`\xff}]\x18F\x1c7\xffF]\xff\x04{pG\xff\xff\xff\xff\x00\xffx`\x00}\x03{a\xff\xff\xff\xff8a{h\x00+\x01\xff\x01}\x03\xff\xff{h\x02"\xff\xff5 {h\x00"\xff\xff4 {h\x1bh\x1ah{h\x1bh"\xff\x01\x02\x1a`\x0f\xff\xff\xff\xff\xff\x02F;i\xff\x1a\x05+\x08\xff{h "Ze{h\x03"\xff\xff5 \x03}\x03x\xff{h\x1bh\x1bh\x03\xff\x01\x03\x00+\xff\xff{h\x1bh\x1bh{azi8K\x13@{a{hZh{h\xffh\x1aC{h\xffh\x1aC{h\x1bi\x1aC{h[i\x1aC{h\xffi\x1aC{h\xffi\x1aC{h\x1bj\x13Czi\x13C{a{h[j\x04+\x07\xff{h\xffj{h\x1bk\x13Czi\x13C{a{h\x1bhzi\x1a`{h\x1bh[i{a{i}\x03\xff\x07\x03{a{h[jzi\x13C{a{h[j\x04+\x17\xff{h\xffjzi\x13C{a{h\xffj\x00+\x0e\xffxh\x00\xffw\xff\x03F\x00+\x08\xff{h@"Ze{h\x01"\xff\xff5 \x01}\x03\x16\xff{h\x1bhziZaxh\x00\xff.\xff\x03F\xff`{h\xffm?"\xff@\xffh\xff`{h\x00"Ze{h\x01"\xff\xff5 \x00}\x03\x18F\x187\xffF\xff\xff?\xff\x10\xff\xff\xff\xff\xff\x00\xff\xff`\xff`z`;`\x00}\x03\xffu\xffh\xffm;a\xffh\xff\xff40\x01+\x01\xff\x02}\x03H\xff\xffh\x01"\xff\xff4 \xffh\xff\xff50\xff\xff\x01+7\xff\xffh\x02"\xff\xff5 \xffh\x00"Ze;hzh\xffh\xffh\x00\xff\xff\xff\xffh\xffm?"\xff@;i\xff`\xffh\x1bh\x1ah\xffh\x1bhB\xff\x16\x02\x1a`\xffh\x1bhZi\xffh\x1bhB\xff\xff\x02Za\xffh\x1bl\x00+\x07\xff\xffh\x1bh\x1ah\xffh\x1bhB\xff\x08\x02\x1a`\xffh\x1bh\x1ah\xffh\x1bhB\xff\x01\x02\x1a`\x05\xff\xffh\x00"\xff\xff4 \x02}\x03\xffu\xff}]\x18F\x187\xffF\xff\xff\xff\xff\xff\xff\x00\xffx`\x00}\x03\xff`\xffK\x1bh\xffJ\xff\xff\x03}\x03\xff\x0a{a{h\xffm;a;i\x1bh\xff`{h\xffm\x08"\xff@\xffh\x13@\x00+\x1a\xff{h\x1bh\x1bh\x03\xff\x04\x03\x00+\x13\xff{h\x1bh\x1ah{h\x1bh"\xff\x04\x02\x1a`{h\xffm\x08"\xff@;i\xff`{h[mC\xff\x01\x02{hZe{h\xffm\x01"\xff@\xffh\x13@\x00+\x12\xff{h\x1bh[i\x03\xff\xff\x03\x00+\x0b\xff{h\xffm\x01"\xff@;i\xff`{h[mC\xff\x02\x02{hZe{h\xffm\x04"\xff@\xffh\x13@\x00+\x12\xff{h\x1bh\x1bh\x03\xff\x02\x03\x00+\x0b\xff{h\xffm\x04"\xff@;i\xff`{h[mC\xff\x04\x02{hZe{h\xffm\x10"\xff@\xffh\x13@\x00+C\xff{h\x1bh\x1bh\x03\xff\x08\x03\x00+<\xff{h\xffm\x10"\xff@;i\xff`{h\x1bh\x1bh\x03\xff\xff}\x03\x00+\x18\xff{h\x1bh\x1bh\x03\xff\x00}\x03\x00+\x08\xff{h\x1bl\x00+}\x04\xff{h\x1blxh\xffG\x1f\xff{h\xffl\x00+\x1b\xff{h\xfflxh\xffG\x16\xff{h\x1bh\x1bh\x03\xff\xffs\x00+\x07\xff{h\x1bh\x1ah{h\x1bh"\xff\x08\x02\x1a`{h\x1bl\x00+\x03\xff{h\x1blxh\xffG{h\xffm "\xff@\xffh\x13@\x00+\x00\xff\xff\xff{h\x1bh\x1bh\x03\xff\x10\x03\x00+\x00\xff\xff\xff{h\xffm "\xff@;i\xff`{h\xff\xff50\xff\xff\x05+6\xff{h\x1bh\x1ah{h\x1bh"\xff\x16\x02\x1a`{h\x1bhZi{h\x1bh"\xff\xff\x02Za{h\x1bl\x00+\x03\xff{h\xffl\x00+\x07\xff{h\x1bh\x1ah{h\x1bh"\xff\x08\x02\x1a`{h\xffm?"\xff@;i\xff`{h\x01"\xff\xff5 {h\x00"\xff\xff4 {h\x1bm\x00+~\xff{h\x1bmxh\xffGy\xff{h\x1bh\x1bh\x03\xff\xff}\x03\x00+\x1d\xff{h\x1bh\x1bh\x03\xff\x00}\x03\x00+\x0d\xff{h[l\x00+1\xff{h[lxh\xffG,\xff\x00\xff\x08\x00\x00 \xff\xffN\x1b{h\xffk\x00+}\x03\xff{h\xffkxh\xffG\x1e\xff{h\x1bh\x1bh\x03\xff\xffs\x00+\x0f\xff{h\x1bh\x1ah{h\x1bh"\xff\x10\x02\x1a`{h\x01"\xff\xff5 {h\x00"\xff\xff4 {h\xffk\x00+\x03\xff{h\xffkxh\xffG{h[m\x00+2\xff{h[m\x03\xff\x01\x03\x00+"\xff{h\x05"\xff\xff5 {h\x1bh\x1ah{h\x1bh"\xff\x01\x02\x1a`\xffh\x013\xff`zi\xffB\x07\xff{h\x1bh\x1bh\x03\xff\x01\x03\x00+\xff\xff\x00\xff\x00\xff{h\x01"\xff\xff5 {h\x00"\xff\xff4 {h\xffl\x00+\x05\xff{h\xfflxh\xffG\x00\xff\x00\xff\x187\xffF\xff\xff\xff\xff\xff\xff\x00\xff\xff`\xff`z`;`\xffh\x1bh\x1ah\xffh\x1bh"\xff\xff"\x1a`\xffh\x1bh:hZ`\xffh\xffh@+\x08\xff\xffh\x1bhzh\xff`\xffh\x1bh\xffh\xff`\x07\xff\xffh\x1bh\xffh\xff`\xffh\x1bhzh\xff`\x00\xff\x147\xffF]\xff\x04{pG\xff\xff\xff\xff\x00\xffx`{h\x1bh\xff\xff\x10;\x13J\xff\xff\x03}\x03\x1b\x09\xff`\x12J\xffh\x13D\x1bx\x1aF{h\xffe\xffh\x03+\x08\xff{h\x1bh\x1aF\x0cK\x13@\x1a\x1d{h\xffe\x06\xff{h\x1bh\x1aF\x08K\x13@zh\xffe{h\xffm\x18F\x147\xffF]\xff\x04{pG\x00\xff\xff\xff\xff\xff\x08J\x02\x08\x00\xff\xff\xff\xff\xff\xff\xff\x00\xffx`\x00}\x03\xffs{h\xffj\xff`{h\xffi\x00+\x1f\xff\xffh\x03+V\xff\x01\xffR\xff}\x03\xff\x00\xffY9\x00\x08k9\x00\x08Y9\x00\x08\xff9\x00\x08{h\xffj\x03\xff\xffs\x00+F\xff\x01}\x03\xffsC\xff{h\xffj\xff\xff\xff\x7f@\xff\x01}\x03\xffs=\xff{h\xffi\xff\xff\x00_!\xff\xffh\x03+7\xff\x01\xffR\xff}\x03\xff\xff9\x00\x08\xff9\x00\x08\xff9\x00\x08\xff9\x00\x08\x01}\x03\xffs0\xff{h\xffj\x03\xff\xffs\x00+%\xff\x01}\x03\xffs"\xff{h\xffj\xff\xff\xff\x7f\x1f\xff\x01}\x03\xffs\x1c\xff\xffh\x02+\x03\xff\xffh\x03+\x03\xff\x18\xff\x01}\x03\xffs\x15\xff{h\xffj\x03\xff\xffs\x00+\x0e\xff\x01}\x03\xffs\x0b\xff\x00\xff\x0a\xff\x00\xff\x08\xff\x00\xff\x06\xff\x00\xff\x04\xff\x00\xff\x02\xff\x00\xff\x00\xff\x00\xff\xff{\x18F\x147\xffF]\xff\x04{pG\x00\xff\xff\xff\xff\xff\x00\xffx`9`\x00}\x03\xffa\x00}\x03{a\x00}\x03;a\x00}\x03\xffa\x00}\x03\xffau\xff\x01"\xffi\x02\xff\x03\xff{a;h\x1bhzi\x13@;a:i{i\xffB@\xffd\xff;h[h\x03\xff\x03\x03\x01+\x05\xff;h[h\x03\xff\x03\x03\x02+0\xff{h\xffh\xffa\xffi[\x00\x03"\x02\xff\x03\xff\xffC\xffi\x13@\xffa;h\xffh\xffi[\x00\x02\xff\x03\xff\xffi\x13C\xffa{h\xffi\xff`{h[h\xffa\x01"\xffi\x02\xff\x03\xff\xffC\xffi\x13@\xffa;h[h\x1b\x09\x03\xff\x01\x02\xffi\x02\xff\x03\xff\xffi\x13C\xffa{h\xffiZ`;h[h\x03\xff\x03\x03\x03+\x17\xff{h\xffh\xffa\xffi[\x00\x03"\x02\xff\x03\xff\xffC\xffi\x13@\xffa;h\xffh\xffi[\x00\x02\xff\x03\xff\xffi\x13C\xffa{h\xffi\xff`;h[h\x03\xff\x03\x03\x02+}\x03\xff\xffi\xff\x08{h\x082S\xff"0\xffa\xffi\x03\xff\x07\x03\xff\x00\x0f"\x02\xff\x03\xff\xffC\xffi\x13@\xffa;h\x1ai\xffi\x03\xff\x07\x03\xff\x00\x02\xff\x03\xff\xffi\x13C\xffa\xffi\xff\x08{h\x082\xffiC\xff"\x10{h\x1bh\xffa\xffi[\x00\x03"\x02\xff\x03\xff\xffC\xffi\x13@\xffa;h[h\x03\xff\x03\x02\xffi[\x00\x02\xff\x03\xff\xffi\x13C\xffa{h\xffi\x1a`;h[h\x03\xff@3\x00+\x00\xff\xff\xfffK[leJC\xff\xffCSdcK[l\x03\xff\xffC\xff`\xffhaJ\xffi\xff\x08\x023R\xff}\x030\xffa\xffi\x03\xff\x03\x03\xff\x00\x0f"\x02\xff\x03\xff\xffC\xffi\x13@\xffa{hXJ\xffB7\xff{hWJ\xffB1\xff{hVJ\xffB+\xff{hUJ\xffB%\xff{hTJ\xffB\x1f\xff{hSJ\xffB\x19\xff{hRJ\xffB\x13\xff{hQJ\xffB\x0d\xff{hPJ\xffB\x07\xff{hOJ\xffB\x01\xff\x09}\x03\x12\xff\x0a}\x03\x10\xff\x08}\x03\x0e\xff\x07}\x03\x0c\xff\x06}\x03\x0a\xff\x05}\x03\x08\xff\x04}\x03\x06\xff\x03}\x03\x04\xff\x02}\x03\x02\xff\x01}\x03\x00\xff\x00}\x03\xffi\x02\xff\x03\x02\xff\x00\xff@\xffi\x13C\xffa5I\xffi\xff\x08\x023\xffiA\xff}\x03 =K\xffh\xffa;i\xffC\xffi\x13@\xffa;h[h\x03\xff\xff\x13\x00+\x03\xff\xffi;i\x13C\xffa4J\xffi\xff`2K\xffh\xffa;i\xffC\xffi\x13@\xffa;h[h\x03\xff\x00\x13\x00+\x03\xff\xffi;i\x13C\xffa)J\xffi\xff`(K[h\xffa;i\xffC\xffi\x13@\xffa;h[h\x03\xff\x003\x00+\x03\xff\xffi;i\x13C\xffa\x1fJ\xffiS`\x1dK\x1bh\xffa;i\xffC\xffi\x13@\xffa;h[h\x03\xff\xff3\x00+\x03\xff\xffi;i\x13C\xffa\x14J\xffi\x13`\xffi\x013\xffa\xffi\x0f+\x7f\xff\xff\xff\x00\xff\x00\xff}\x047\xffF]\xff\x04{pG\x00\xff\x008\x02@\x008\x01@\x00\x00\x02@\x00\x04\x02@\x00\x08\x02@\x00\x0c\x02@\x00\x10\x02@\x00\x14\x02@\x00\x18\x02@\x00\x1c\x02@\x00 \x02@\x00}\x04\x02@\x00<\x01@\xff\xff\xff\xff\x00\xffx`9`\x00}\x03;a\x00}\x03\xff`\x00}\x03\xff`\x00}\x03{a\xff\xff\x01"{i\x02\xff\x03\xff;a:h;i\x13@\xff`\xffh;i\xffB@\xff\xff\xffkJ{i\xff\x08\x023R\xff}\x030\xff`{i\x03\xff\x03\x03\xff\x00\x0f"\x02\xff\x03\xff\xffh\x13@\xff`{hcJ\xffB7\xff{hbJ\xffB1\xff{haJ\xffB+\xff{h`J\xffB%\xff{h_J\xffB\x1f\xff{h^J\xffB\x19\xff{h]J\xffB\x13\xff{h\\J\xffB\x0d\xff{h[J\xffB\x07\xff{hZJ\xffB\x01\xff\x09}\x03\x12\xff\x0a}\x03\x10\xff\x08}\x03\x0e\xff\x07}\x03\x0c\xff\x06}\x03\x0a\xff\x05}\x03\x08\xff\x04}\x03\x06\xff\x03}\x03\x04\xff\x02}\x03\x02\xff\x01}\x03\x00\xff\x00}\x03zi\x02\xff\x03\x02\xff\x00\xff@\xffh\xffB2\xffKK\x1ah\xffh\xffCII\x13@\x0b`HKZh\xffh\xffCFI\x13@K`DK\xffh\xffh\xffCBI\x13@\xff`AK\xffh\xffh\xffC?I\x13@\xff`{i\x03\xff\x03\x03\xff\x00\x0f"\x02\xff\x03\xff\xff`.J{i\xff\x08\x023R\xff}\x03\x10\xffh\xffC}\x0aH{i\xff\x08\x0a@\x023@\xff}\x03 {h\x1ah{i[\x00\x03!\x01\xff\x03\xff\xffC\x1a@{h\x1a`{i\xff\x08{h\x082S\xff"\x10{i\x03\xff\x07\x03\xff\x00\x0f"\x02\xff\x03\xff\xffCzi\xff\x08\x19@{h\x082C\xff"\x10{h\xffh{i[\x00\x03!\x01\xff\x03\xff\xffC\x1a@{h\xff`{hZh\x01!{i\x01\xff\x03\xff\xffC\x1a@{hZ`{h\xffh{i[\x00\x03!\x01\xff\x03\xff\xffC\x1a@{h\xff`{i\x013{a{i\x0f+\x7f\xff"\xff\x00\xff\x00\xff\x1c7\xffF]\xff\x04{pG\x00\xff\x008\x01@\x00\x00\x02@\x00\x04\x02@\x00\x08\x02@\x00\x0c\x02@\x00\x10\x02@\x00\x14\x02@\x00\x18\x02@\x00\x1c\x02@\x00 \x02@\x00}\x04\x02@\x00<\x01@\xff\xff\xff\xff\x00\xffx`\x0bF{\xff{h\x1ai{\xff\x13@\x00+\x02\xff\x01}\x03\xffs\x01\xff\x00}\x03\xffs\xff{\x18F\x147\xffF]\xff\x04{pG\xff\xff\xff\xff\x00\xffx`\x0bF{\xff\x13F{p{x\x00+\x03\xffz\xff{h\xffa\x03\xff{\xff\x1a\x04{h\xffa\x00\xff\x0c7\xffF]\xff\x04{pG\xff\xff\xff\xff\x00\xffx`\x0bF{\xff{h[i\xff`z\xff\xffh\x13@\x1a\x04\xffh\xffC{\xff\x0b@\x1aC{h\xffa\x00\xff\x147\xffF]\xff\x04{pG\x00\x00\xff\xff\xff\xff\x00\xffx`{h\x00+\x01\xff\x01}\x03\x7f\xff{h\xff\xffA0\xff\xff\x00+\x06\xff{h\x00"\xff\xff@ xh\xff\xffR\xff{h}\x04"\xff\xffA {h\x1bh\x1ah{h\x1bh"\xff\x01\x02\x1a`{hZh{h\x1bh"\xffpb\x1aa{h\x1bh\xffh{h\x1bh"\xff\x00B#3f
[6.509] handleFlashPacket():  Flash write: Address= 0x80001d0, Length=16048
[6.509] write():  <756> Tx: $OK#9a
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

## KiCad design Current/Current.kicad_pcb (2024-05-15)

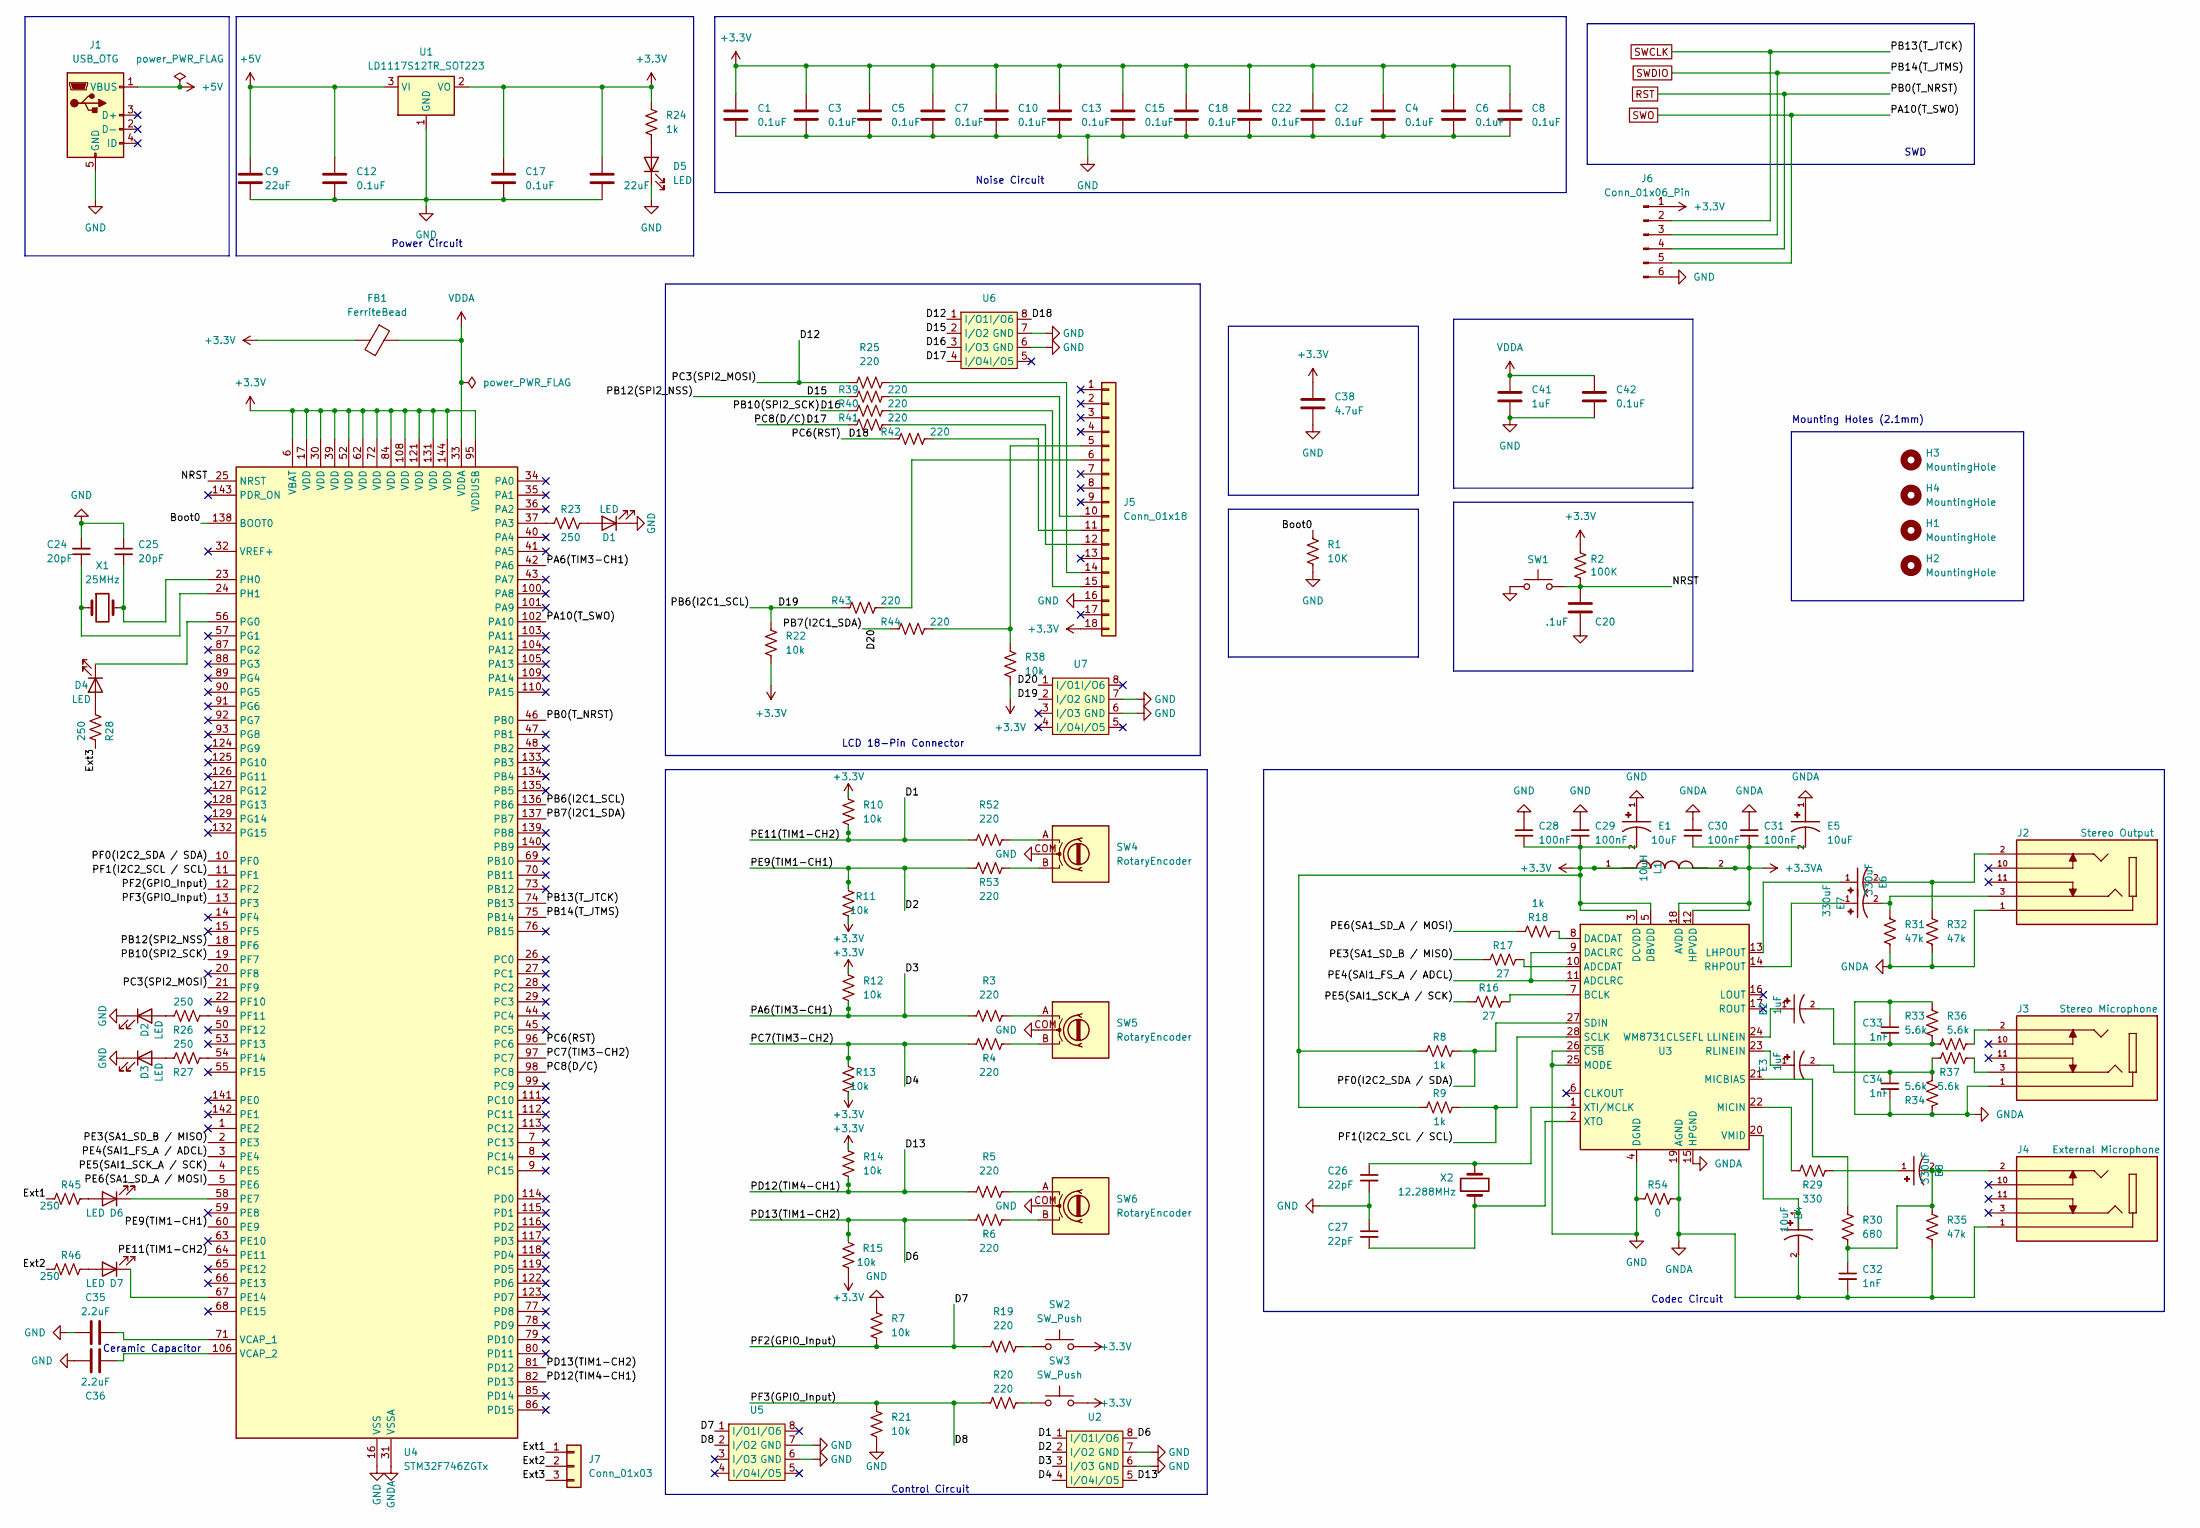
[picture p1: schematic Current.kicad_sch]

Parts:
C1, C2, C3, C4, C5, C6, C7, C8, C10, C12, C13, C15, C17, C18, C22, C42: 0.1uF; C_0805_2012Metric
C9, C21: 22uF; C_0805_2012Metric
C20: .1uF; C_0805_2012Metric
C24, C25: 20pF; C_0805_2012Metric
C26, C27: 22pF; C_0805_2012Metric
C28, C29, C30, C31: 100nF; C_0805_2012Metric
C32, C33, C34: 1nF; C_0805_2012Metric
C35, C36: 2.2uF; C_0805_2012Metric
C38: 4.7uF; C_0805_2012Metric
C41: 1uF; C_0805_2012Metric
D1, D2, D3, D4, D5, D6, D7: LED; LED_0805_2012Metric
E1, E4, E5: 10uF; CAPPM3528X210N; PARTREV N/A
E2, E3: 1uF; CAP_EEEFC1V1R0R; PARTREV 10-Oct-19
E6, E7, E8: 330uF; CAP_EEEFT0J331AP; PARTREV 10-Oct-19
FB1: FerriteBead; BEADC1608X75N
H1, H2, H3, H4: MountingHole; MountingHole_4.5mm
J1: USB_OTG; AMPHENOL_10118193-0001LF
J2: Stereo Output; CUI_SJ1-3515-SMT; PARTREV 1.05
J3: Stereo Microphone; CUI_SJ1-3515-SMT; PARTREV 1.05
J4: External Microphone; CUI_SJ1-3515-SMT; PARTREV 1.05
J5: Conn_01x18; CON_527461871_MOL
J6: Conn_01x06_Pin; PinSocket_1x06_P2.54mm_Vertical
J7: Conn_01x03; PinSocket_1x03_P2.54mm_Vertical
L1: 10uH; IND_SLF7045T-100M1R3-PF; PARTREV N/A
R1: 10K; R_0805_2012Metric
R2: 100K; R_0805_2012Metric
R3, R4, R5, R6, R19, R20, R25, R39, R40, R41, R42, R43, R44, R52, R53: 220; R_0805_2012Metric
R7, R10, R11, R12, R13, R14, R15, R21, R22, R38: 10k; R_0805_2012Metric
R8, R9, R18, R24: 1k; R_0805_2012Metric
R16, R17: 27; R_0805_2012Metric
R23, R26, R27, R28, R45, R46: 250; R_0805_2012Metric
R29: 330; R_0805_2012Metric
R30: 680; R_0805_2012Metric
R31, R32, R35: 47k; R_0805_2012Metric
R33, R34, R36, R37: 5.6k; R_0805_2012Metric
R54: 0; R_0805_2012Metric
SW1, SW2, SW3: SW_Push; SW_B3F-4050
SW4, SW5, SW6: RotaryEncoder; XDCR_PEC11R-4215F-S0024
U1: LD1117S12TR_SOT223; SOT-223-3_TabPin2
U2, U5, U6, U7: SO-8_3.9x4.9mm_P1.27mm
U3: WM8731CLSEFL; QFN-28-1EP_5x5mm_P0.5mm_EP3.35x3.35mm
U4: STM32F746ZGTx; LQFP-144_20x20mm_P0.5mm
X1: 25MHz; XTAL_ABM7-25.000MHZ-D2Y-T
X2: 12.288MHz; XTAL_HCM4924000000ABJT

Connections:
+3.3V: C1.1, C2.1, C3.1, C4.1, C5.1, C6.1, C7.1, C8.1, C10.1, C13.1, C15.1, C17.1, C18.1, C21.1, C22.1, C28.2, C29.2, C38.1, E1.2, FB1.2, J5.18, J6.1, L1.1, R2.1, R8.1, R9.1, R10.1, R11.1, R12.1, R13.1, R14.1, R15.1, R22.1, R24.2, R38.1, SW2.2, SW3.2, U1.2 (VO), U3.3 (DCVDD), U3.5 (DBVDD), U4.6 (VBAT), U4.17 (VDD), U4.30 (VDD), U4.39 (VDD), U4.52 (VDD), U4.62 (VDD), U4.72 (VDD), U4.84 (VDD), U4.95 (VDDUSB), U4.108 (VDD), U4.121 (VDD), U4.131 (VDD), U4.144 (VDD)
+3.3VA: C30.2, C31.2, E5.2, L1.2, U3.12 (HPVDD), U3.18 (AVDD)
+5V: C9.1, C12.1, J1.1 (VBUS), U1.3 (VI)
/Boot0: R1.1, U4.138 (BOOT0)
/D1: R10.2, R52.1, U2.1 (I/O1), U4.64 (PE11)
/D2: R11.2, R53.1, U2.2 (I/O2), U4.60 (PE9)
/D3: R3.1, R12.2, U2.3 (I/O3), U4.42 (PA6)
/D4: R4.1, R13.2, U2.4 (I/O4), U4.97 (PC7)
/D6: R6.1, R15.2, U2.8 (I/O6), U4.81 (PD12)
/D7: R7.1, R19.1, U4.12 (PF2), U5.1 (I/O1)
/D8: R20.1, R21.2, U4.13 (PF3), U5.2 (I/O2)
/D12: R25.1, U4.21 (PF9), U6.1 (I/O1)
/D13: R5.1, R14.2, U2.5 (I/O5), U4.82 (PD13)
/D15: R39.1, U4.18 (PF6), U6.2 (I/O2)
/D16: R40.1, U4.19 (PF7), U6.3 (I/O3)
/D17: R41.1, U4.98 (PC8), U6.4 (I/O4)
/D18: R42.1, U4.96 (PC6), U6.8 (I/O6)
/D19: R22.2, R43.1, U4.136 (PB6), U7.2 (I/O2)
/D20: R44.1, U4.137 (PB7), U7.1 (I/O1)
/Ext1: J7.1, R45.2
/Ext2: J7.2, R46.2
/Ext3: J7.3, R28.1
/NRST: C20.1, R2.2, SW1.2, U4.25 (NRST)
/PE3(SA1_SD_B / MISO): R17.2, U4.2 (PE3)
/PE4(SAI1_FS_A / ADCL): U3.9 (DACLRC), U3.11 (ADCLRC), U4.3 (PE4)
/PE5(SAI1_SCK_A / SCK): R16.2, U4.4 (PE5)
/PE6(SA1_SD_A / MOSI): R18.2, U4.5 (PE6)
/PF0(I2C2_SDA / SDA): R8.2, U3.27 (SDIN), U4.10 (PF0)
/PF1(I2C2_SCL / SCL): R9.2, U3.28 (SCLK), U4.11 (PF1)
GND: C1.2, C2.2, C3.2, C4.2, C5.2, C6.2, C7.2, C8.2, C9.2, C10.2, C12.2, C13.2, C15.2, C17.2, C18.2, C20.2, C21.2, C22.2, C24.2, C25.1, C26.2, C27.1, C28.1, C29.1, C35.1, C36.1, C38.2, C41.2, C42.2, D1.1 (K), D2.1 (K), D3.1 (K), D5.1 (K), E1.1, J1.5 (GND), J5.16, J6.6, R1.2, R7.2, R21.1, R54.1, SW1.1, SW4.COM (C), SW5.COM (C), SW6.COM (C), U1.1 (GND), U2.6 (GND), U2.7 (GND), U3.4 (DGND), U3.25 (MODE), U3.26 (~CSB), U4.16 (VSS), U4.38 (VSS), U4.51 (VSS), U4.61 (VSS), U4.83 (VSS), U4.94 (VSS), U4.107 (VSS), U4.120 (VSS), U4.130 (VSS), U5.6 (GND), U5.7 (GND), U6.6 (GND), U6.7 (GND), U7.6 (GND), U7.7 (GND)
GNDA: C30.1, C31.1, C32.2, C33.1, C34.2, E4.2, E5.1, J2.1, J3.1, J4.1, R31.2, R32.2, R33.1, R34.1, R35.2, R54.2, U3.15 (HPGND), U3.19 (AGND), U3.29 (AGND), U4.31 (VSSA)
unnamed: C32.1, E8.2, J4.2, R30.2, R35.1
unnamed: C33.2, E2.2, R33.2, R36.2
unnamed: C34.1, E3.2, R34.2, R37.1
unnamed: D1.2 (A), R23.1
unnamed: D2.2 (A), R26.1
unnamed: D3.2 (A), R27.1
unnamed: D4.2 (A), R28.2
unnamed: D4.1 (K), U4.56 (PG0)
unnamed: D5.2 (A), R24.1
unnamed: D6.2 (A), R45.1
unnamed: D6.1 (K), U4.58 (PE7)
unnamed: D7.2 (A), R46.1
unnamed: D7.1 (K), U4.67 (PE14)
unnamed: E6.2, J2.2, R32.1
unnamed: E7.2, J2.3, R31.1
unnamed: E8.1, R29.2
unnamed: J3.2, R36.1
unnamed: J3.3, R37.2
unnamed: J5.5, R38.2, R44.2
unnamed: J5.6, R43.2
unnamed: J5.10, R39.2
unnamed: J5.11, R42.2
unnamed: J5.12, R41.2
unnamed: J5.14, R25.2
unnamed: J5.15, R40.2
unnamed: R3.2, SW5.A
unnamed: R4.2, SW5.B
unnamed: R5.2, SW6.A
unnamed: R6.2, SW6.B
unnamed: R19.2, SW2.1
unnamed: R20.2, SW3.1
unnamed: R52.2, SW4.A
unnamed: R53.2, SW4.B
unnamed: R17.1, U3.10 (ADCDAT)
unnamed: R16.1, U3.7 (BCLK)
unnamed: R18.1, U3.8 (DACDAT)
unnamed: E6.1, U3.13 (LHPOUT)
unnamed: E2.1, U3.24 (LLINEIN)
unnamed: R30.1, U3.21 (MICBIAS)
unnamed: R29.1, U3.22 (MICIN)
unnamed: E7.1, U3.14 (RHPOUT)
unnamed: E3.1, U3.23 (RLINEIN)
unnamed: E4.1, U3.20 (VMID)
unnamed: C26.1, U3.1 (XTI/MCLK), X2.2
unnamed: C27.2, U3.2 (XTO), X2.1
unnamed: R23.2, U4.37 (PA3)
unnamed: R26.2, U4.49 (PF11)
unnamed: R27.2, U4.54 (PF14)
unnamed: C25.2, U4.23 (PH0), X1.2
unnamed: C24.1, U4.24 (PH1), X1.1
unnamed: C35.2, U4.71 (VCAP_1)
unnamed: C36.2, U4.106 (VCAP_2)
RST: J6.4, U4.46 (PB0)
SWCLK: J6.2, U4.74 (PB13)
SWDIO: J6.3, U4.75 (PB14)
SWO: J6.5, U4.102 (PA10)
VDDA: C41.1, C42.1, FB1.1, U4.33 (VDDA)

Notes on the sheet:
Ceramic Capacitor
Control Circuit
LCD 18-Pin Connector
Mounting Holes (2.1mm)
Power Circuit
Codec Circuit
Noise Circuit
SWD

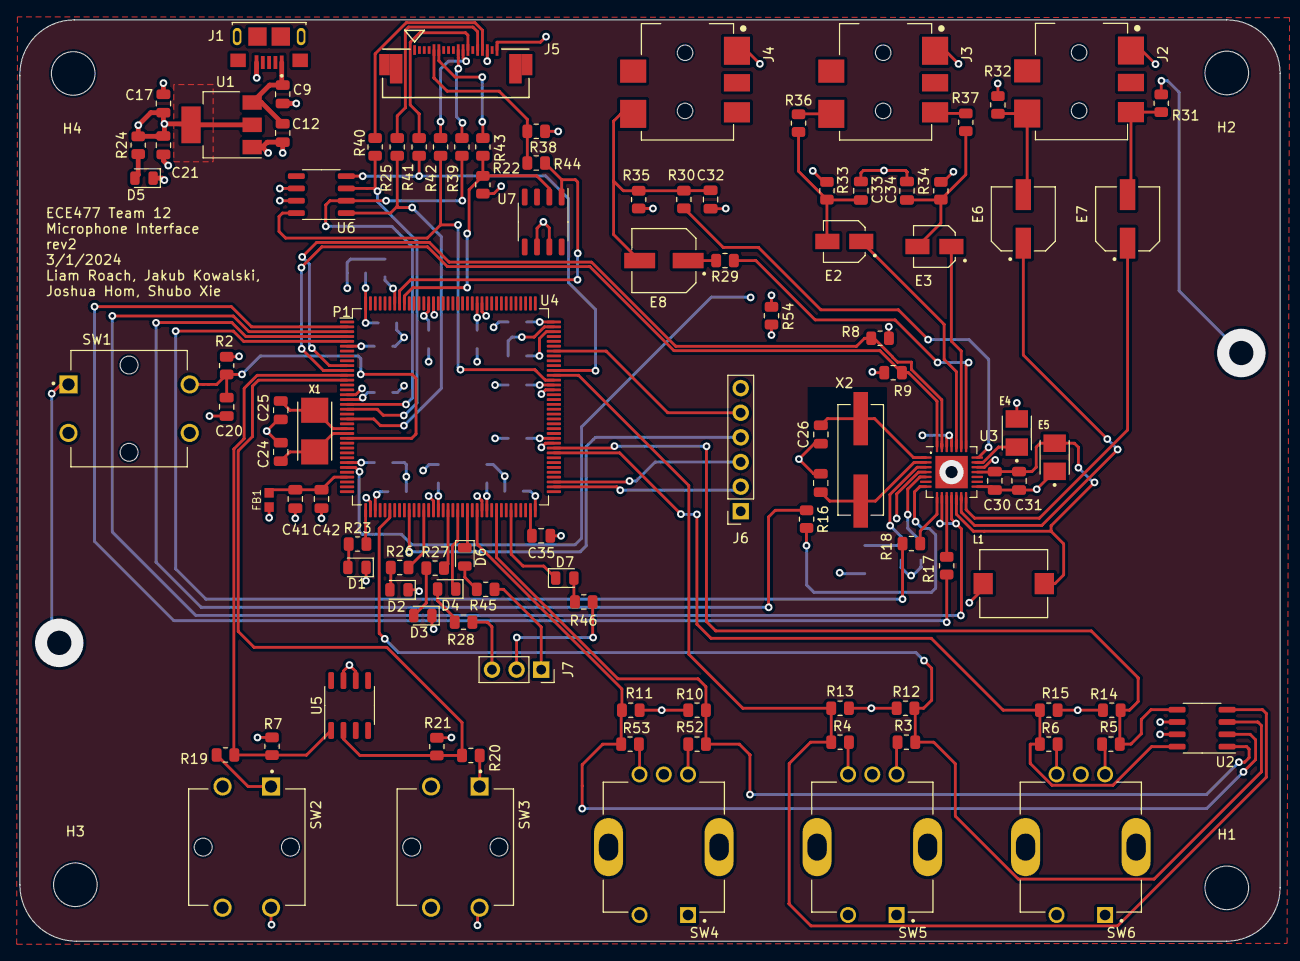
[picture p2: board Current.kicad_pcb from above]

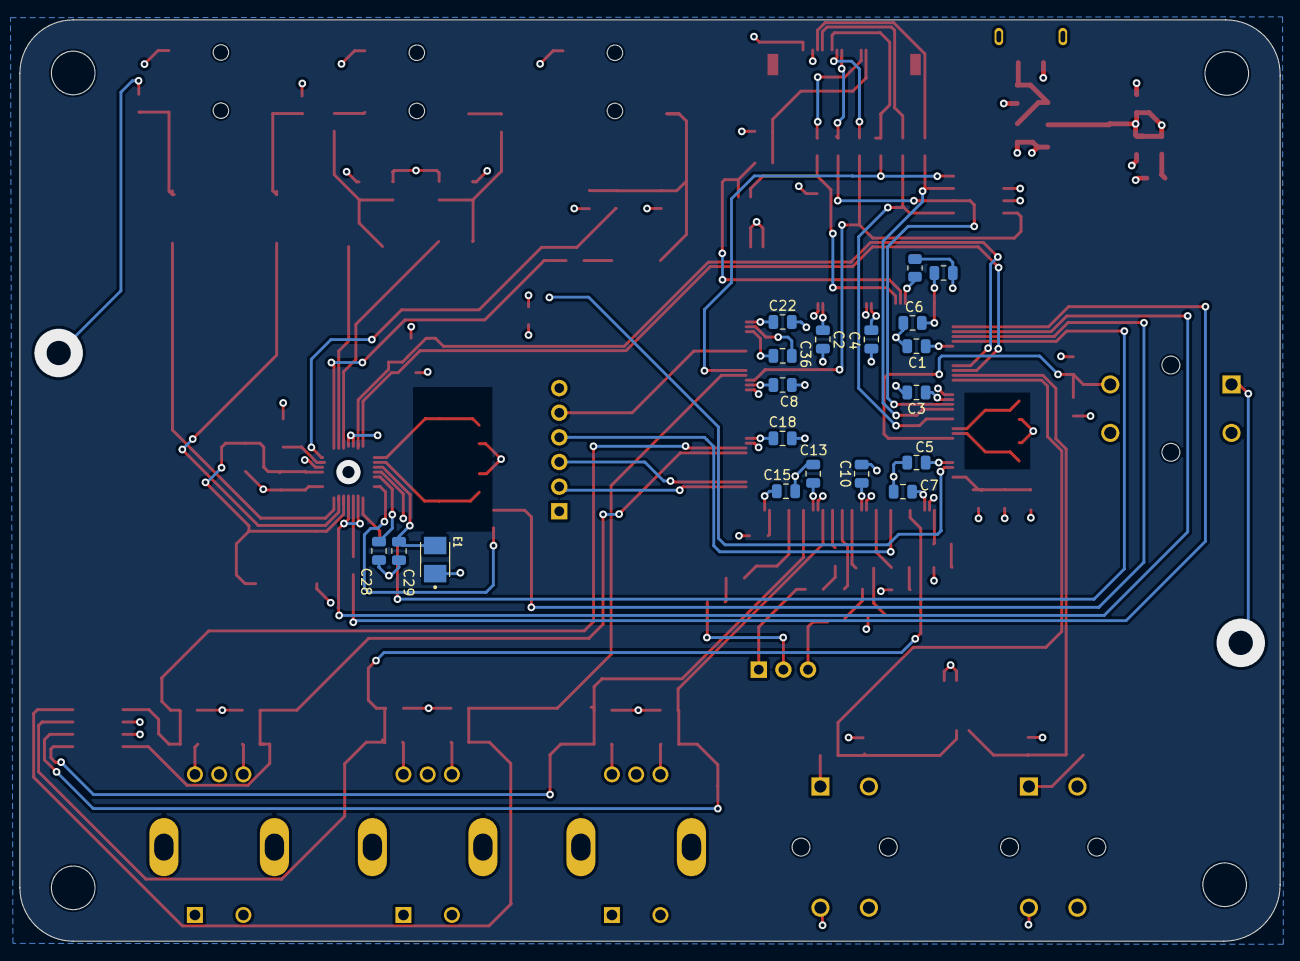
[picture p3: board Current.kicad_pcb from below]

Board: 4 copper layers, 129.9 x 95.0 mm, 126 parts (19 on the bottom side), 88 nets.

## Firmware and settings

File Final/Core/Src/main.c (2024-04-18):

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
/* Includes ------------------------------------------------------------------*/
#include "main.h"
#include "app_touchgfx.h"

/* USER CODE BEGIN Includes */
#include "wm8731.h"
#include "stdio.h"
#include "audioFX.h"
#include "filters.h"
#include "delay.h"
#include "distort.h"
#include "ili9341.h"
#include "trig_functions.h"
/* USER CODE END Includes */


CRC_HandleTypeDef hcrc;

I2C_HandleTypeDef hi2c1;
I2C_HandleTypeDef hi2c2;

SAI_HandleTypeDef hsai_BlockA1;
SAI_HandleTypeDef hsai_BlockB1;
DMA_HandleTypeDef hdma_sai1_a;
DMA_HandleTypeDef hdma_sai1_b;

SPI_HandleTypeDef hspi5;
DMA_HandleTypeDef hdma_spi5_tx;

TIM_HandleTypeDef htim1;
TIM_HandleTypeDef htim2;
TIM_HandleTypeDef htim3;
TIM_HandleTypeDef htim4;
TIM_HandleTypeDef htim14;

/* USER CODE BEGIN PV */
int select = 0; //LED Select
int state[2] = {0, 0}; //States for LR Buttons
int tDelay[3] = {50,50,50}; //Delays from Counters
int ConfLvl[2] = {0,0};
int ConfT = 750;

// DMA buffers
int16_t audio_in[AUDIOFX_BUFF_SIZE];
int16_t audio_out[AUDIOFX_BUFF_SIZE];

int16_t* p_in_buff;
int16_t* p_out_buff;

// change fx flag
uint8_t change_fx_flag;

// parameter change variables
uint16_t timer_count[3];

FILTERS_Params f_p0;
FILTERS_Params f_p1;
FILTERS_Params f_p2;
FILTERS_Params f_p3;
FILTERS_Params f_p4;

DELAY_Params dl_p;

DISTORT_Params ds_p;

AUDIOFX_Type curr_fx;

uint8_t update_flags;
/* USER CODE END PV */

void SystemClock_Config(void);
void PeriphCommonClock_Config(void);
static void MX_GPIO_Init(void);
static void MX_DMA_Init(void);
static void MX_TIM14_Init(void);
static void MX_TIM3_Init(void);
static void MX_TIM4_Init(void);
static void MX_CRC_Init(void);
static void MX_TIM1_Init(void);
static void MX_TIM2_Init(void);
static void MX_I2C1_Init(void);
static void MX_SPI5_Init(void);
static void MX_I2C2_Init(void);
static void MX_SAI1_Init(void);
/* USER CODE BEGIN PFP */

int _write(int file, char *ptr, int len)
{
  /* Implement your write code here. This is
     used by puts and printf for example */
  int i=0;
  for(i=0 ; i<len ; i++)
    ITM_SendChar((*ptr++));
  return len;
}

/* USER CODE END PFP */

/* USER CODE BEGIN 0 */
void HAL_SAI_RxHalfCpltCallback(SAI_HandleTypeDef *hsai) {
	if(hsai->Instance == SAI1_Block_A){
		p_in_buff	= &audio_in[0];
		p_out_buff 	= &audio_out[0];

		AUDIOFX_Apply_FX_Chain();
	}
}

void HAL_SAI_RxCpltCallback(SAI_HandleTypeDef *hsai) {
	if(hsai->Instance == SAI1_Block_A){
		p_in_buff	= &audio_in[AUDIOFX_BUFF_SIZE/2];
		p_out_buff 	= &audio_out[AUDIOFX_BUFF_SIZE/2];

		AUDIOFX_Apply_FX_Chain();
	}
}

static void Param_Change(){
	// Check that counter is in the accepted range
	if(TIM1->CNT > AUDIOFX_CNTR_MAX) {
		TIM1->CNT = AUDIOFX_CNTR_MAX;
	}
	else if(TIM1->CNT < AUDIOFX_CNTR_MIN) {
		TIM1->CNT = AUDIOFX_CNTR_MIN;
	}

	if(TIM3->CNT > AUDIOFX_CNTR_MAX) {
		TIM3->CNT = AUDIOFX_CNTR_MAX;
	}
	else if(TIM3->CNT < AUDIOFX_CNTR_MIN) {
		TIM3->CNT = AUDIOFX_CNTR_MIN;
	}

	if(TIM4->CNT > AUDIOFX_CNTR_MAX) {
		TIM4->CNT = AUDIOFX_CNTR_MAX;
	}
	else if(TIM4->CNT < AUDIOFX_CNTR_MIN) {
		TIM4->CNT = AUDIOFX_CNTR_MIN;
	}

	// check for difference in timer values
	if(TIM1->CNT != timer_count[0] || TIM3->CNT != timer_count[1] || TIM4->CNT != timer_count[2]) {
		// store counter values
		timer_count[0] = TIM1->CNT;
		timer_count[1] = TIM3->CNT;
		timer_count[2] = TIM4->CNT;

		AUDIOFX_SetParams(curr_fx);
	}
}

static void FX_Change() {
	if(HAL_GPIO_ReadPin(GPIOF, GPIO_PIN_2) == 1){
		ConfLvl[0]++;
		if(ConfLvl[0] > ConfT){
			while(HAL_GPIO_ReadPin(GPIOF, GPIO_PIN_2) == 1)
			ConfLvl[0] = 0;
			AUDIOFX_SwitchFX(0);
		}
	}
	if(HAL_GPIO_ReadPin(GPIOF, GPIO_PIN_3) == 1){
		ConfLvl[1]++;
		if(ConfLvl[1] > ConfT){
			while(HAL_GPIO_ReadPin(GPIOF, GPIO_PIN_3) == 1)
			ConfLvl[1] = 0;
			AUDIOFX_SwitchFX(1);
		}
	}

	// check if we changed current FX using touch screen
	if(change_fx_flag) {
		AUDIOFX_UpdateCounters();
		change_fx_flag = 0;
	}
}


/* USER CODE END 0 */

/**
  * @brief  The application entry point.
  * @retval int
  */
int main(void)
{
  /* MCU Configuration--------------------------------------------------------*/

  /* Reset of all peripherals, Initializes the Flash interface and the Systick. */
  HAL_Init();

  /* Configure the system clock */
  SystemClock_Config();

/* Configure the peripherals common clocks */
  PeriphCommonClock_Config();

  /* Initialize all configured peripherals */
  MX_GPIO_Init();
  MX_DMA_Init();
  MX_TIM14_Init();
  MX_TIM3_Init();
  MX_TIM4_Init();
  MX_CRC_Init();
  MX_TIM1_Init();
  MX_TIM2_Init();
  MX_I2C1_Init();
  MX_SPI5_Init();
  MX_I2C2_Init();
  MX_SAI1_Init();
  MX_TouchGFX_Init();
  /* USER CODE BEGIN 2 */

  update_flags 	= 0;
  curr_fx 	  	= AUDIOFX_FILTER0;

  FILTERS_Init(&f_p0);
  FILTERS_Init(&f_p1);
  FILTERS_Init(&f_p2);
  FILTERS_Init(&f_p3);
  FILTERS_Init(&f_p4);

  DELAY_Init(&dl_p);
  DISTORT_Init(&ds_p);

  ILI9341_Init();
  WM8731_Init();

//  HAL_GPIO_TogglePin(GPIOF, GPIO_PIN_11);

  HAL_SAI_Receive_DMA(&hsai_BlockA1, (uint8_t*) audio_in, AUDIOFX_BUFF_SIZE);
  HAL_SAI_Transmit_DMA(&hsai_BlockB1, (uint8_t*) audio_out, AUDIOFX_BUFF_SIZE);

  HAL_TIM_Base_Start_IT(&htim2);

  HAL_TIM_Encoder_Start(&htim1, TIM_CHANNEL_ALL);
  HAL_TIM_Encoder_Start(&htim3, TIM_CHANNEL_ALL);
  HAL_TIM_Encoder_Start(&htim4, TIM_CHANNEL_ALL);

  AUDIOFX_UpdateCounters();
  /* USER CODE END 2 */

  /* Infinite loop */
  /* USER CODE BEGIN WHILE */
  while (1)
  {
    /* USER CODE END WHILE */

  MX_TouchGFX_Process();
    /* USER CODE BEGIN 3 */
  FX_Change();
  Param_Change();
  }
  /* USER CODE END 3 */
}

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
/* USER CODE BEGIN 4 */
extern void touchgfxSignalVSync(void);

void crement_select(int way){
	if(select == 0 && (way == -1)){select = 2;}
	else if(select == 2 && (way == 1)){select = 0;}
	else select = select + way;
}

void HAL_GPIO_EXTI_Callback(uint16_t GPIO_Pin){
}

void HAL_TIM_PeriodElapsedCallback(TIM_HandleTypeDef *htim){
	if (htim->Instance == TIM2) {
		touchgfxSignalVSync();
	}
}
/* USER CODE END 4 */
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


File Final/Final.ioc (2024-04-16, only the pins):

Mcu.UserName=STM32F746ZGTx
PA13.Signal=SYS_JTMS-SWDIO
PA14.Signal=SYS_JTCK-SWCLK
PA3.GPIO_Label=LED1
PA3.Signal=GPIO_Output
PA6.Signal=S_TIM3_CH1
PB6.Signal=I2C1_SCL
PB7.Signal=I2C1_SDA
PC3.Signal=SPI2_MOSI
PC6.GPIO_Label=RST
PC6.Signal=GPIO_Output
PC7.Signal=S_TIM3_CH2
PC8.GPIO_Label=D/C
PC8.Signal=GPIO_Output
PD12.Signal=S_TIM4_CH1
PD13.Signal=S_TIM4_CH2
PE11.Signal=S_TIM1_CH2
PE3.Signal=SAI1_SD_B
PE4.Signal=SAI1_FS_A
PE5.Signal=SAI1_SCK_A
PE6.Signal=SAI1_SD_A
PE9.Signal=S_TIM1_CH1
PF0.Signal=I2C2_SDA
PF1.Signal=I2C2_SCL
PF11.GPIO_Label=LED2
PF11.Signal=GPIO_Output
PF14.GPIO_Label=LED3
PF14.Signal=GPIO_Output
PF2.GPIO_Label=LeftButton
PF2.Signal=GPIO_Input
PF3.GPIO_Label=Right Button
PF3.Signal=GPIO_Input
PF6.Signal=SPI5_NSS
PF7.Signal=SPI5_SCK
PF9.Signal=SPI5_MOSI
PH0/OSC_IN.Signal=RCC_OSC_IN
PH1/OSC_OUT.Signal=RCC_OSC_OUT

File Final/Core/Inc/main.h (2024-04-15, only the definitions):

#define LeftButton_Pin GPIO_PIN_2
#define LeftButton_GPIO_Port GPIOF
#define Right_Button_Pin GPIO_PIN_3
#define Right_Button_GPIO_Port GPIOF
#define LED1_Pin GPIO_PIN_3
#define LED1_GPIO_Port GPIOA
#define LED2_Pin GPIO_PIN_11
#define LED2_GPIO_Port GPIOF
#define LED3_Pin GPIO_PIN_14
#define LED3_GPIO_Port GPIOF
#define RST_Pin GPIO_PIN_6
#define RST_GPIO_Port GPIOC
#define D_C_Pin GPIO_PIN_8
#define D_C_GPIO_Port GPIOC
#define I2C1_SCL_GPIO_PORT GPIOB
#define I2C1_SCL_PIN 6
#define I2C1_SDA_GPIO_PORT GPIOB
#define I2C1_SDA_PIN 7
#define SPI5_NSS_GPIO_Port GPIOF
#define SPI5_NSS_Pin 6
#define SPI5_SCK_GPIO_Port GPIOF
#define SPI5_SCK_Pin 7
#define SPI5_MOSI_GPIO_Port GPIOF
#define SPI5_MOSI_Pin 9
#define INT16_TO_FLOAT (1.0f / 32768.0f)
#define FLOAT_TO_INT16 (32768.0f)
#define AUDIOFX_SAMPLING_RATE 		48000.0f
#define AUDIOFX_SAMPLING_TIME_MS 	(10.0)
#define AUDIOFX_BUFF_SIZE	 		(int) ((AUDIOFX_SAMPLING_TIME_MS / 1000.0) * AUDIOFX_SAMPLING_RATE)
#define UPDATE_FILTER0	0b00000001
#define UPDATE_FILTER1	0b00000010
#define UPDATE_FILTER2	0b00000100
#define UPDATE_FILTER3	0b00001000
#define UPDATE_FILTER4	0b00010000
#define UPDATE_DELAY	0b00100000
#define UPDATE_DISTORT	0b01000000

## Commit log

2024-04-10 added in lcd interface w/ encoders
2024-04-16 ui complete, touchscreen navigation, encoder limits, button debouncing
2024-05-14 Revert "cleanup"
    This reverts commit 3fe7bf66a595cfb90ba8a6e7212a57d9f045a3b8.
    [Final.ioc, main.c]
2024-05-15 unzipped kicad folder
    [Current-B_Cu.gbr, Current-B_Mask.gbr, Current-B_Paste.gbr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]

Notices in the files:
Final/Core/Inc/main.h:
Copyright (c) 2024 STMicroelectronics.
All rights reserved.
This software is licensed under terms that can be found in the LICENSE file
